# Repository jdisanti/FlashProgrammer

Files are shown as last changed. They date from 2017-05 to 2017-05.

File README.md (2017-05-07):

128KiB 17-bit Addressed 32-pin Flash ROM Programmer
---------------------------------------------------

Flash Programmer

This package includes the schematic, PCB design, and software for an USB
Flash Programmer to read/write the contents of 128KiB 32-pin Flash ROM chips,
such as the GLS27SF010 by Greenliant.

This is my second electronics project, and a stepping stone to building my
own 8-bit computer. I made a lot of mistakes along the way and learned a ton.
After four PCB revisions, and hours of frustrating debugging, I finally got it
to successfully erase, write, and verify the contents of a ROM.

## Demo

flash_programmer_software_anim

## Project Structure

The `avr/` directory contains all of the software to be run on the Atmel
ATMEGA328 chip on the board. This needs to be compiled and programmed onto
the board using an ISP on the ISP headers.

The `design/` directory contains the schematic and PCB design in the original
KiCad file formats. The BOM file is also here.

The `PDFs/` directory contains PDF output for the schematic and PCB.

The `software/` directory contains the software that runs on the PC to
communicate with the device over USB serial. It's written in Rust and can
be compiled/run on Linux, Mac, and Windows without a hitch.

Finally, `symbol_generation/` contains some CSV files used to generate
schematic symbols with KiPart.

## What I Learned

This project presented a lot of firsts for me. My previous project, a binary
clock, had taught me how to design a digital circuit with a microcontroller,
draw schematics, and create PCBs.

This project, above all other things, taught me patience. If you read the
next section about the mistakes I made, you'll see why. I learned that I
really need to slow down, be sure to read all of the datasheets, double
check my schematics and footprints, and cross-check my schematic against
the datasheets. Then after all of that, wait a week and then do it again.

Coming from a software background made this a very hard lesson. I'm used to
making small incremental changes and getting test results immediately. Working
in an area where incremental changes are expensive, and where testing is
time-consuming, requires a difficult change of mindset.

Something I didn't do with this project was breadboarding. I wanted to see
if I could design and build a working circuit without that step. I've learned
that I can play around with little "mock" circuits in LTSpice to test some
of my assumptions, and then also build those out on breadboard without having
to build the entire circuit. This was useful for designing the A9 signal/12V
switching circuit.

## Mistakes I Made

Since the goal of this project was to learn, I've decided to document all
the mistakes I made for future reference.

**First board (not in version control)**
- I didn't read the entire datasheet for the MAX662A, and thus, didn't realize
  I needed capacitors on the 12V output. This led to there being no 12V supply
  on that board.
- I tried to be clever and soldered the board up in sections so I could test each
  individually. This is how I discovered the 12V supply wasn't working, but I didn't
  continue testing the other sections after that discovery, and thus, didn't
  discover my next mistake until the next board.

**Second board**
- I got the pins on the SOT-23 2N3906 transistor wrong, and lost a decent
  chunk of time debugging that, and then soldering it on upside-down to fix it.
- I discovered that I couldn't use the daisy chaining pin on the 74HC595
  as the 17th bit of the address. I should have looked at the timing diagram
  in the datasheet to verify my assumption. I was actually able to bodge this
  by severing the A16 line and wiring it to the three unused pins on the micro
  (and setting all three pins to the same output since they were tied together).
- I used the ISP pins for both programming the MCU and talking to the ROM chip,
  but I neglected to add resistors so that I could program the MCU while the
  ROM chip was populated on the board. Unfortunately, I didn't realize this at
  the time, and thought I had fried my MCU somehow. Since I had already discovered
  the address line mistake, I just built another revision instead of doing
  more testing (I didn't have a rework station at the time and didn't want to
  solder another board either).

**Third board**
- I discovered that erasing didn't work because I failed to realize that
  the 12V had to be applied to both the VPP and A9 pins during the erase process.

**Fourth board**
- I didn't put a pull-down resistor on the A9 signal after the diodes. This
  forced me to add a hefty delay loop of 160uS in the code that set the address.
  This mistake is still present in the design since it wasn't fatal.

## License

All of the contents of this package are licensed under the Solderpad 0.51
license. Please read the LICENSE.md included for more details.

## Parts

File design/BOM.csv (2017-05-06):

Id | Designator | Package | Quantity | Designation | Supplier and ref
1 | P601 | Pin_Header_Straight_2x03_Pitch2.54mm | 1 | ISP
2 | P201 | USB_B | 1 | USB_B
3 | Q301 | SOT-23_Handsoldering | 1 | 2N3904
4 | D301,D302 | D_SOT-23_ANK | 2 | BAT54
5 | C201,C206,C301,C501,C502,C601,C602,C603 | R_0603_HandSoldering | 8 | 100nF
6 | C202 | R_0603_HandSoldering | 1 | 10nF
7 | C203,C401,C402 | R_0805_HandSoldering | 3 | 4.7uF
8 | C204,C205 | R_0603_HandSoldering | 2 | 47pF
9 | C403,C404 | R_0603_HandSoldering | 2 | 22nF
10 | D701,D702,D703 | LED_0805 | 3 | LED
11 | L201 | R_0805_HandSoldering | 1 | Ferrite_Bead
12 | Q701 | SOT-23_Handsoldering | 1 | 2N3906
13 | R201,R202 | R_0603_HandSoldering | 2 | 27
14 | R301 | R_0603_HandSoldering | 1 | 1k
15 | R302,R501,R502,R602,R704 | R_0603_HandSoldering | 5 | 10k
16 | R601,R603,R604,R605 | R_0603_HandSoldering | 4 | 4.7k
17 | R701,R702,R703 | R_0603_HandSoldering | 3 | 150
18 | U201 | SSOP-16 | 1 | FT230X
19 | U301 | DIP-32_W15.24mm | 1 | GLS27SF010
20 | U401 | SOIC-8_3.9x4.9mm_Pitch1.27mm | 1 | MAX662A
21 | U501,U502 | SOIC-16_3.9x9.9mm_Pitch1.27mm | 2 | 74HC595
22 | U601 | TQFP-32 | 1 | ATMEGA328-AU

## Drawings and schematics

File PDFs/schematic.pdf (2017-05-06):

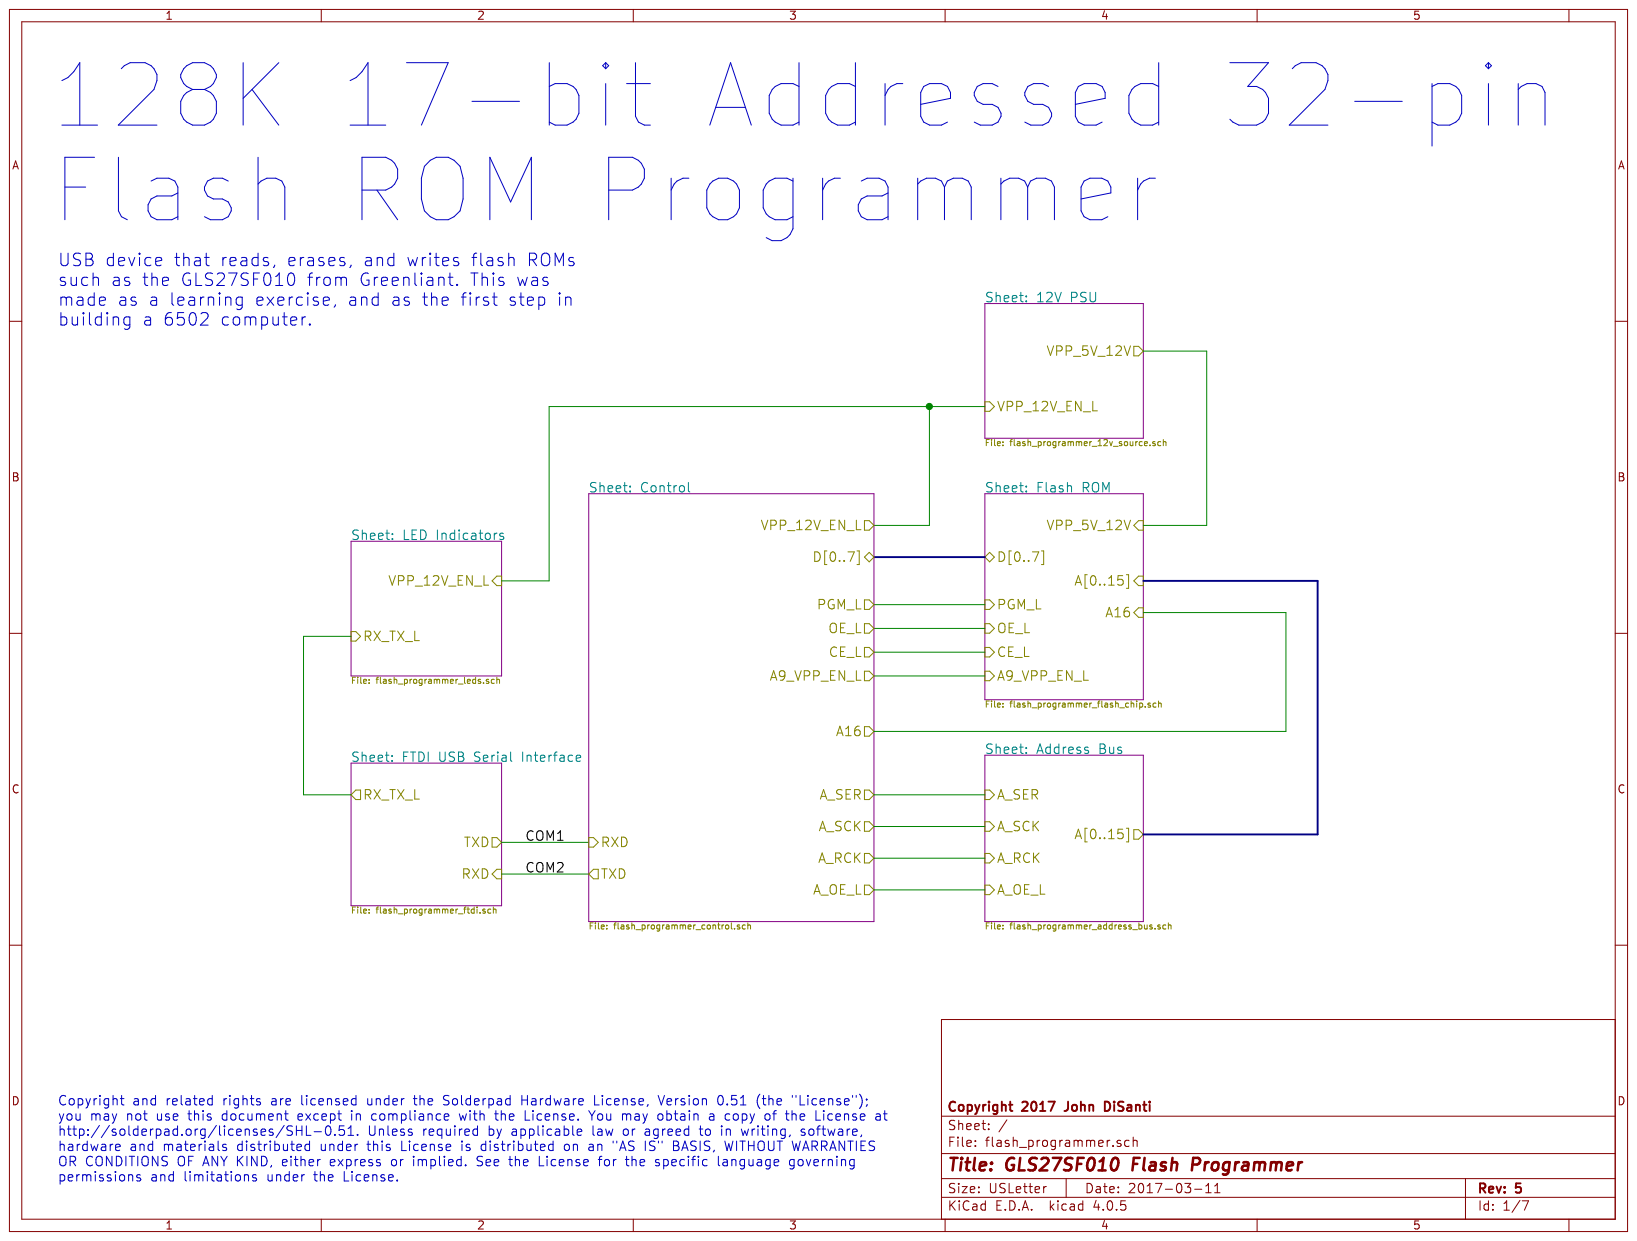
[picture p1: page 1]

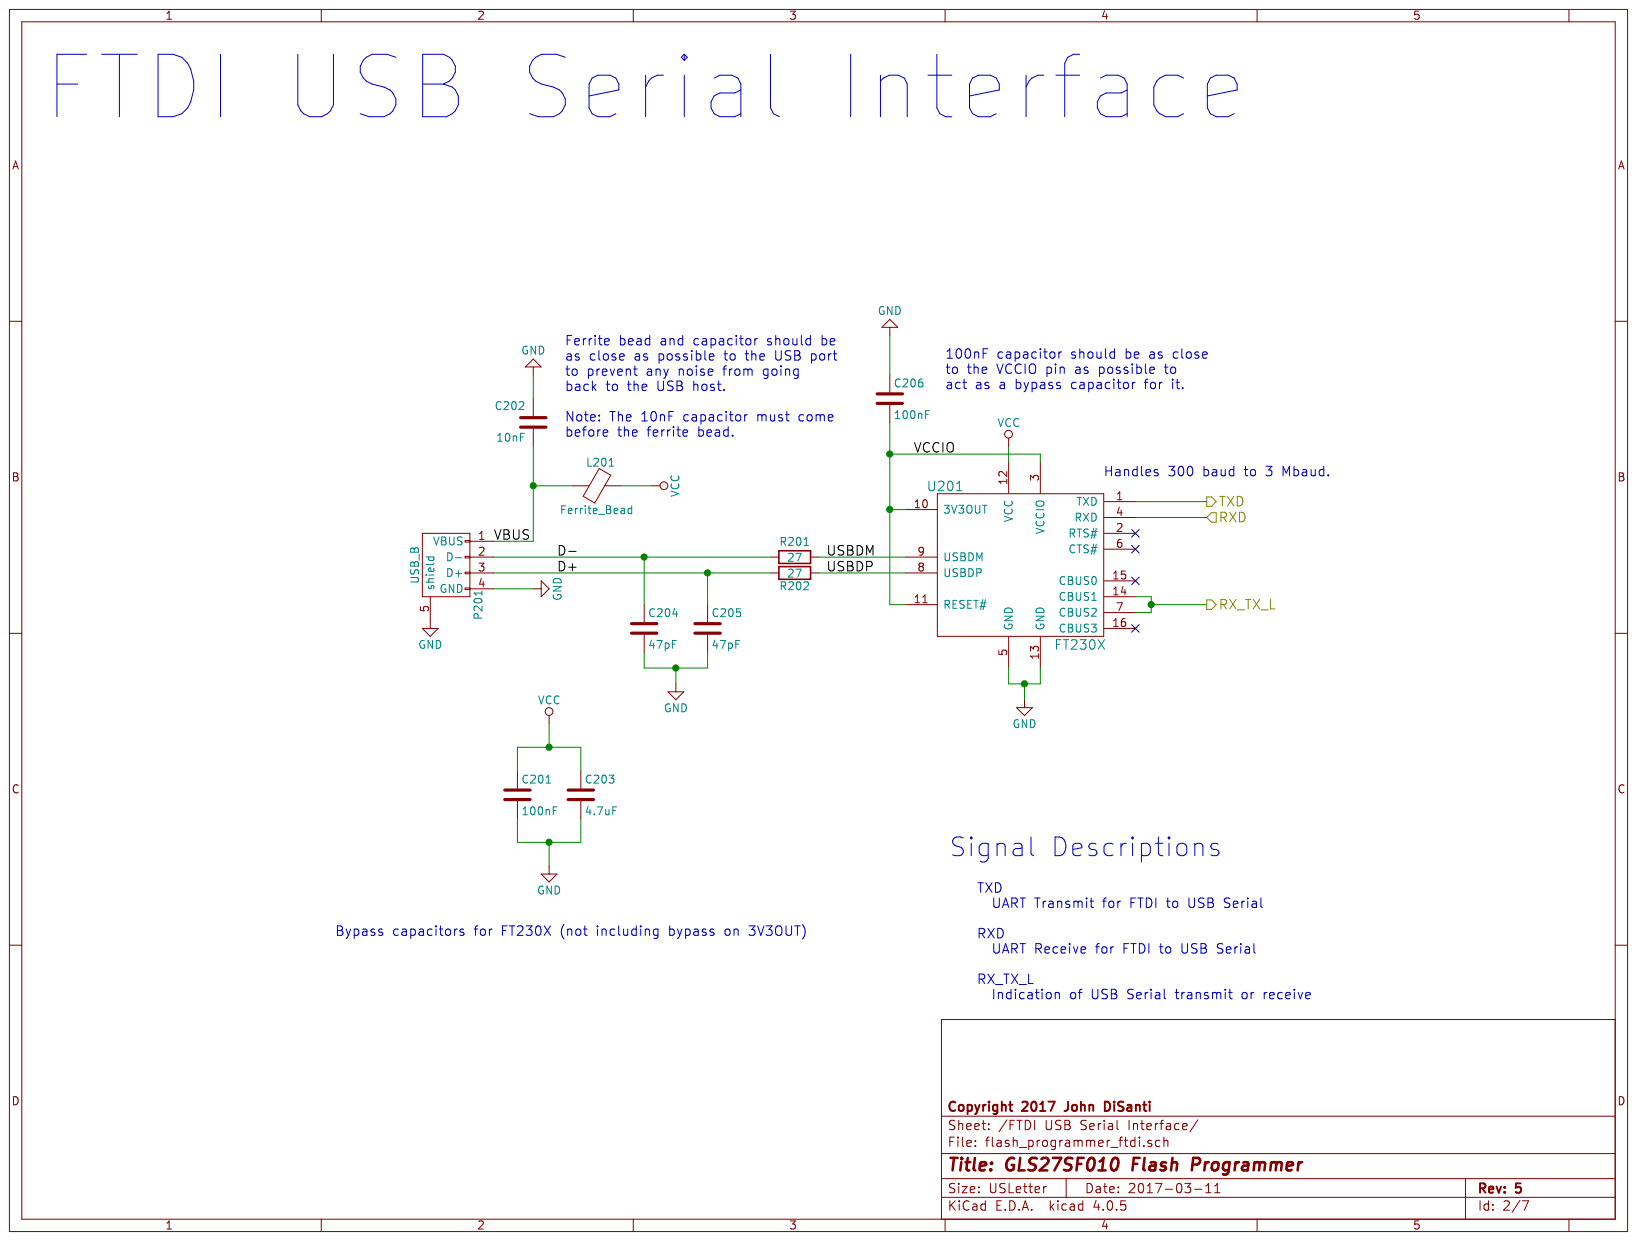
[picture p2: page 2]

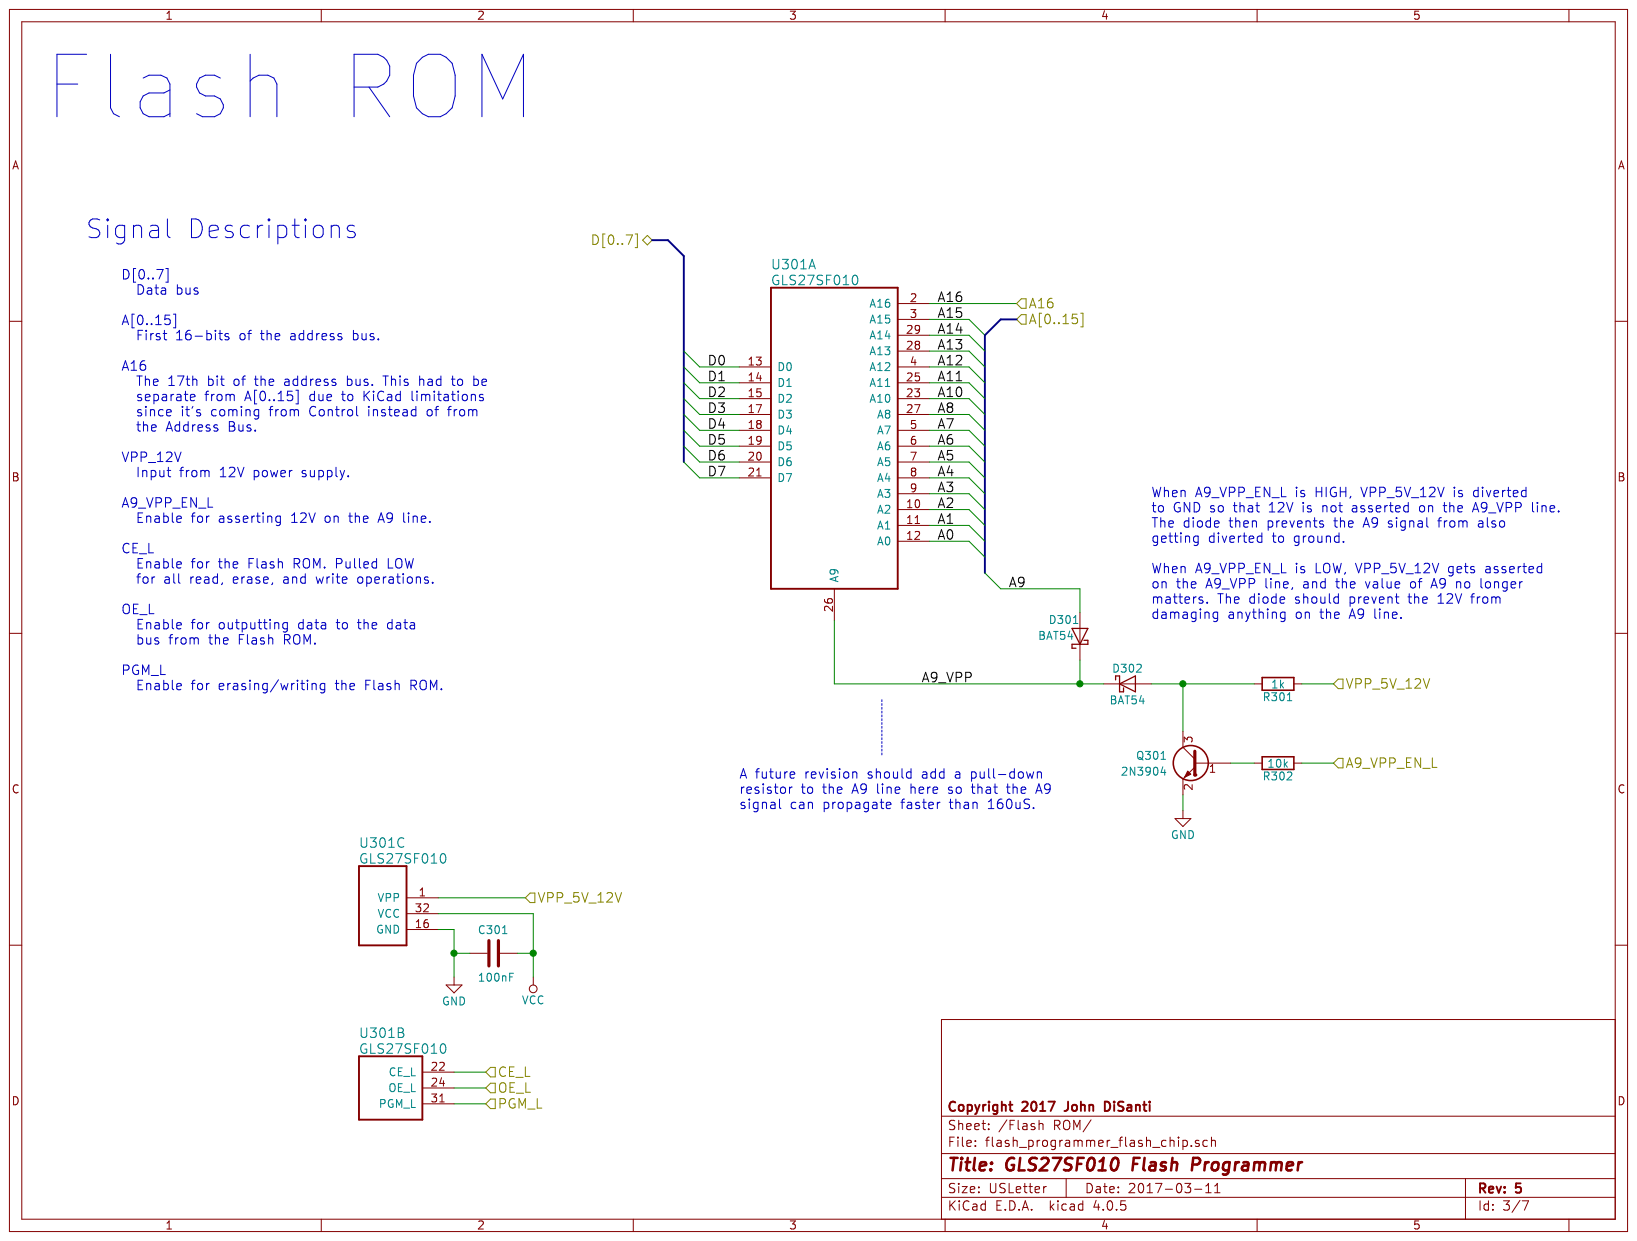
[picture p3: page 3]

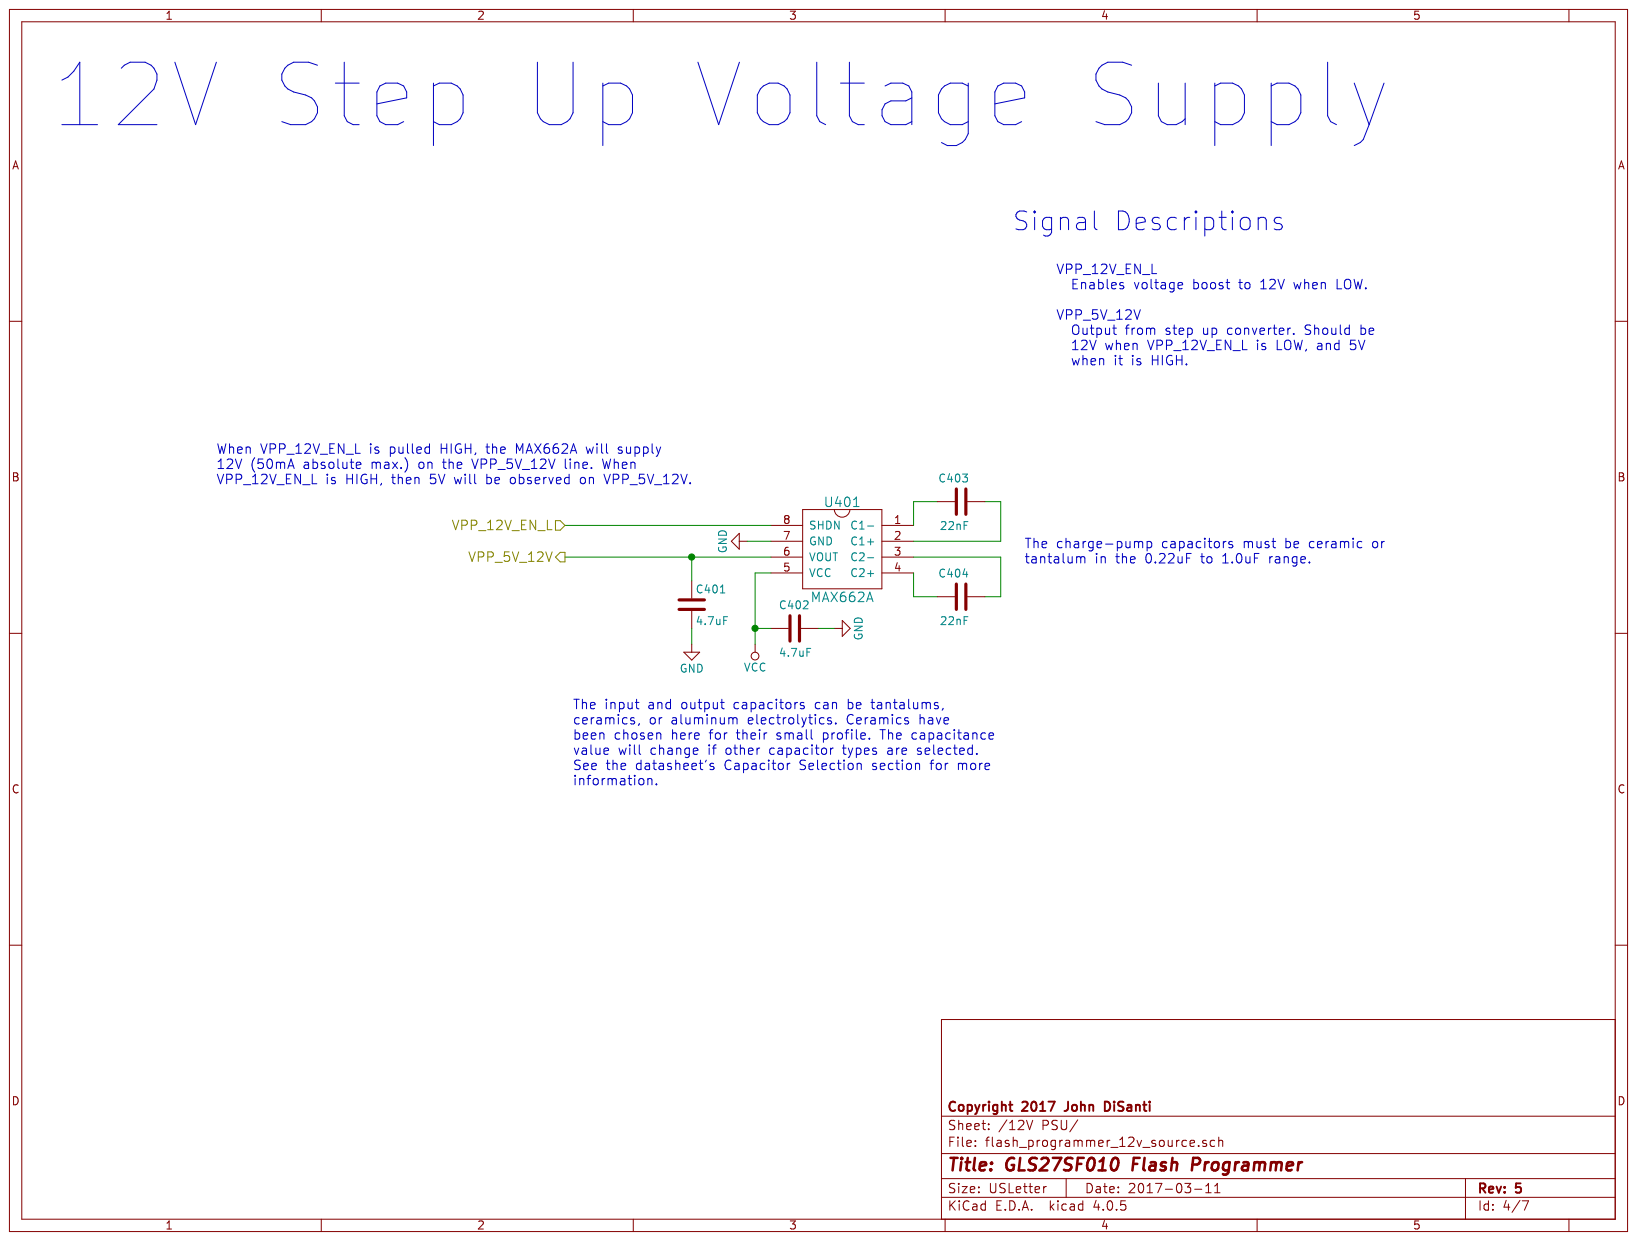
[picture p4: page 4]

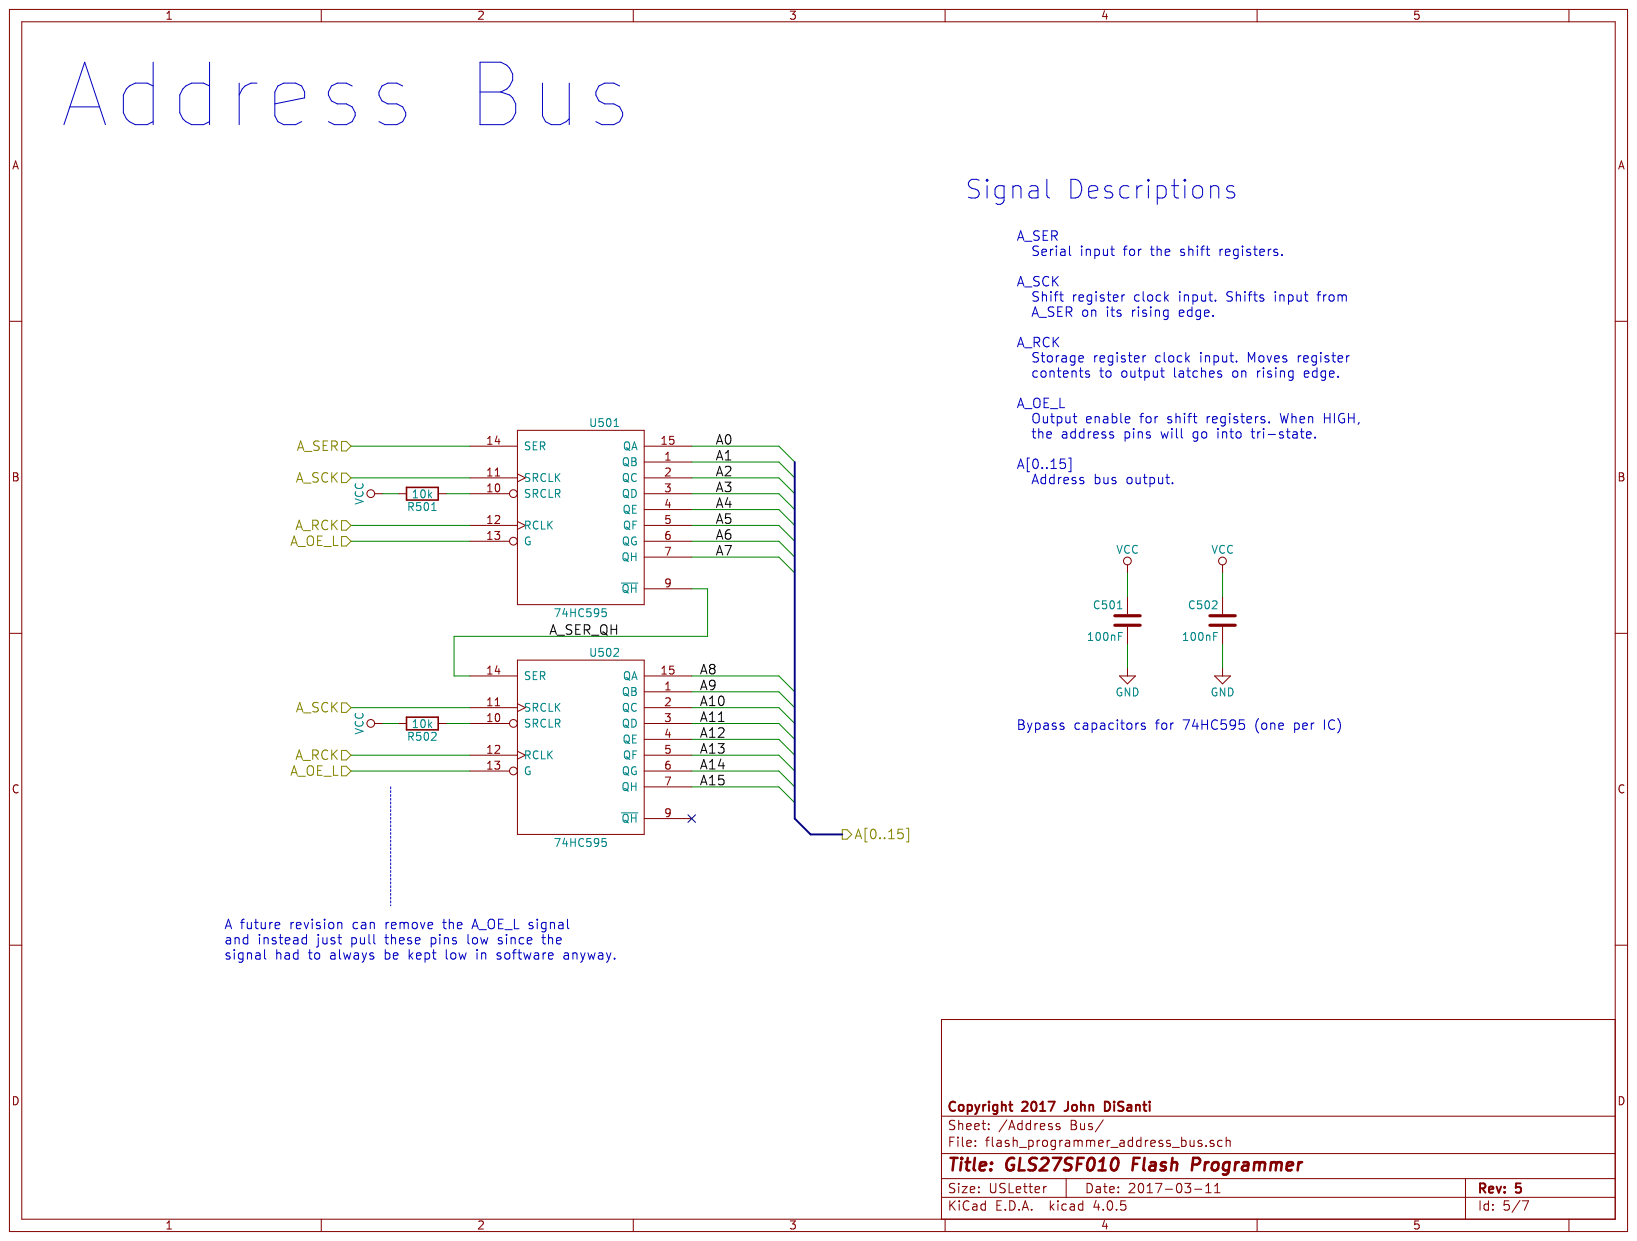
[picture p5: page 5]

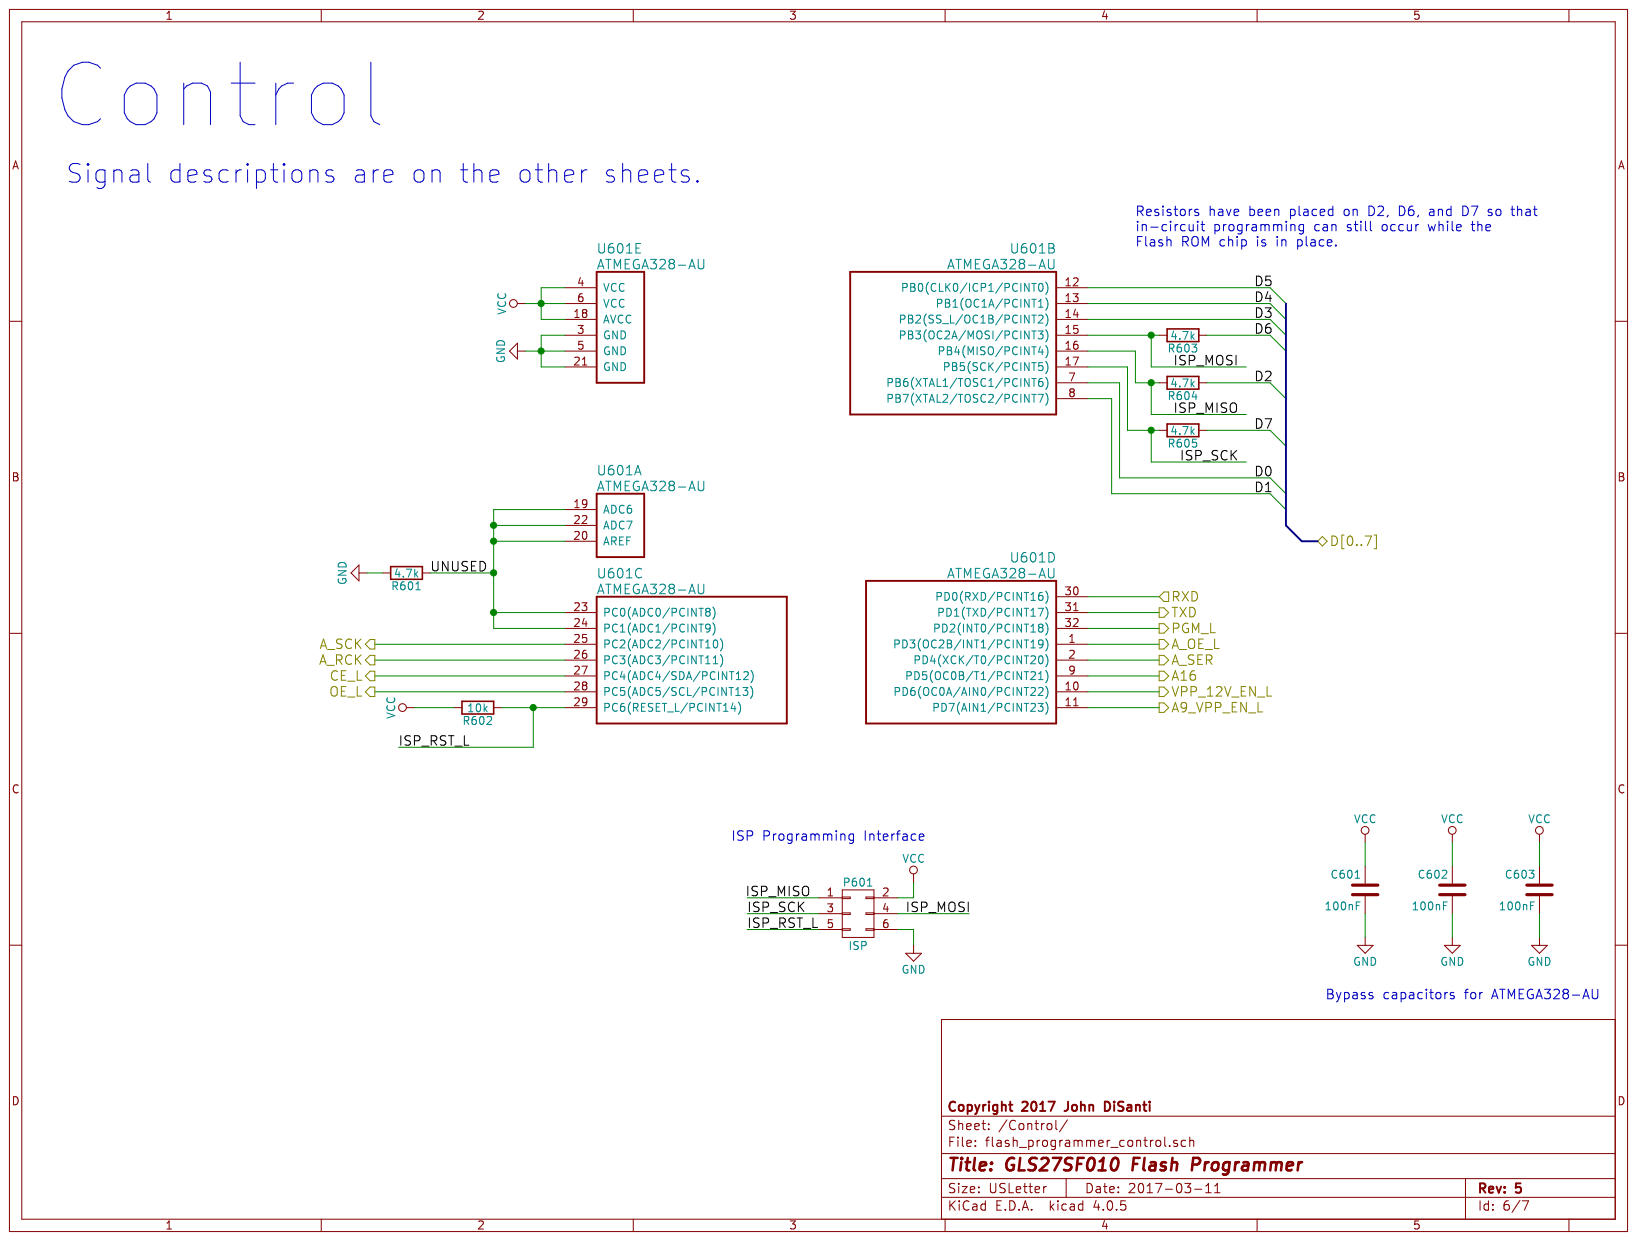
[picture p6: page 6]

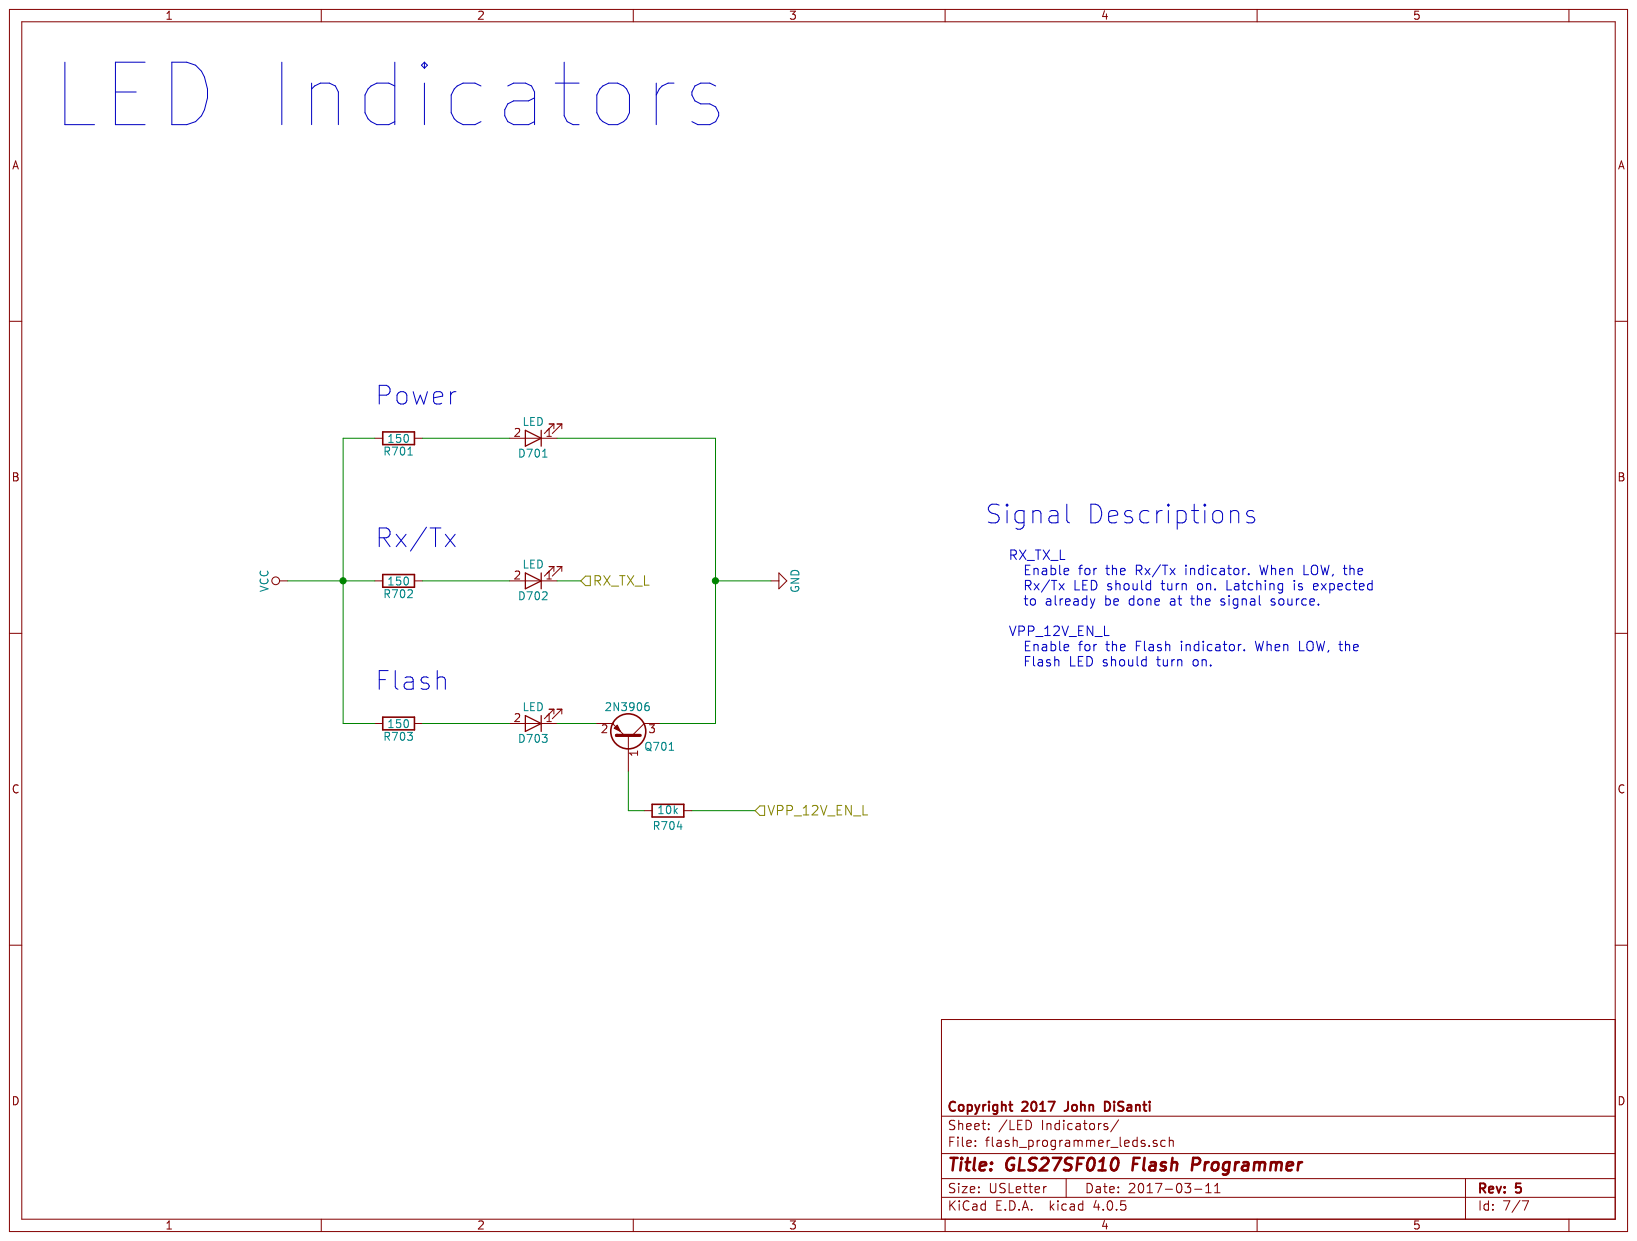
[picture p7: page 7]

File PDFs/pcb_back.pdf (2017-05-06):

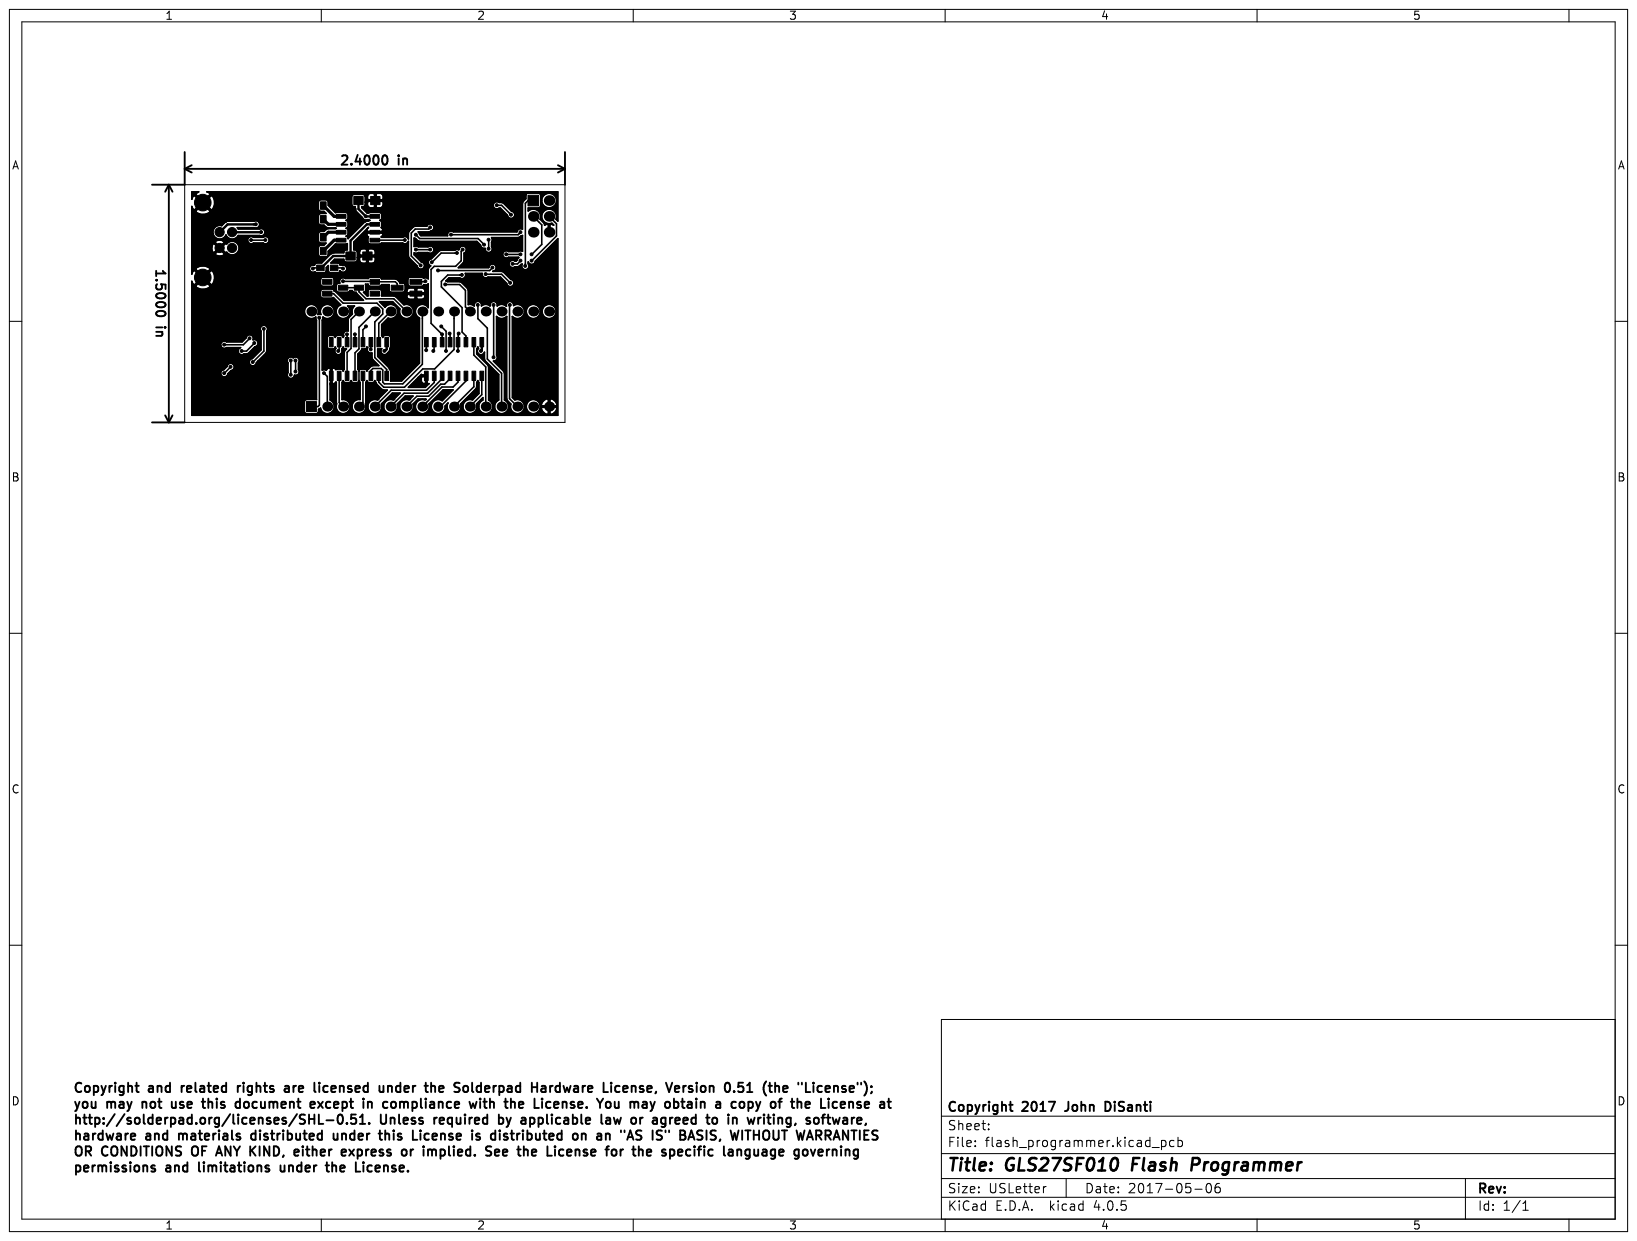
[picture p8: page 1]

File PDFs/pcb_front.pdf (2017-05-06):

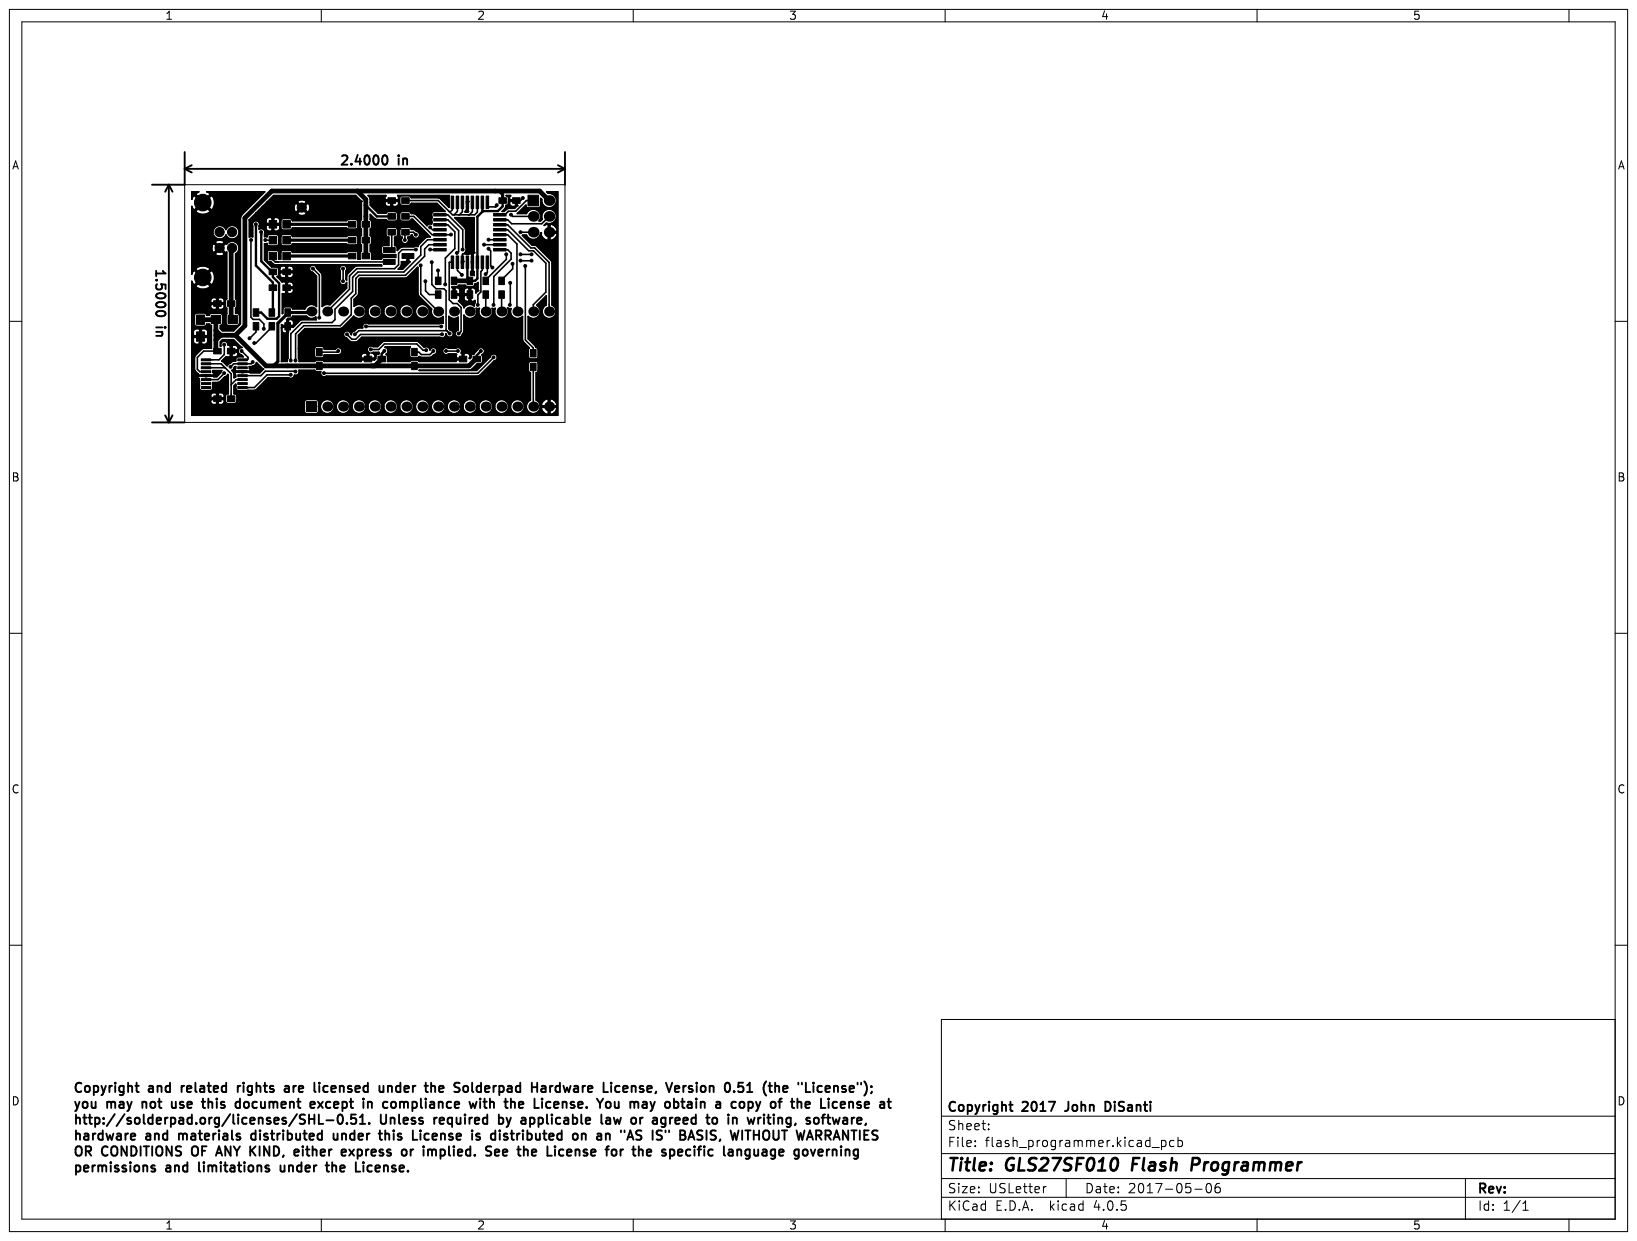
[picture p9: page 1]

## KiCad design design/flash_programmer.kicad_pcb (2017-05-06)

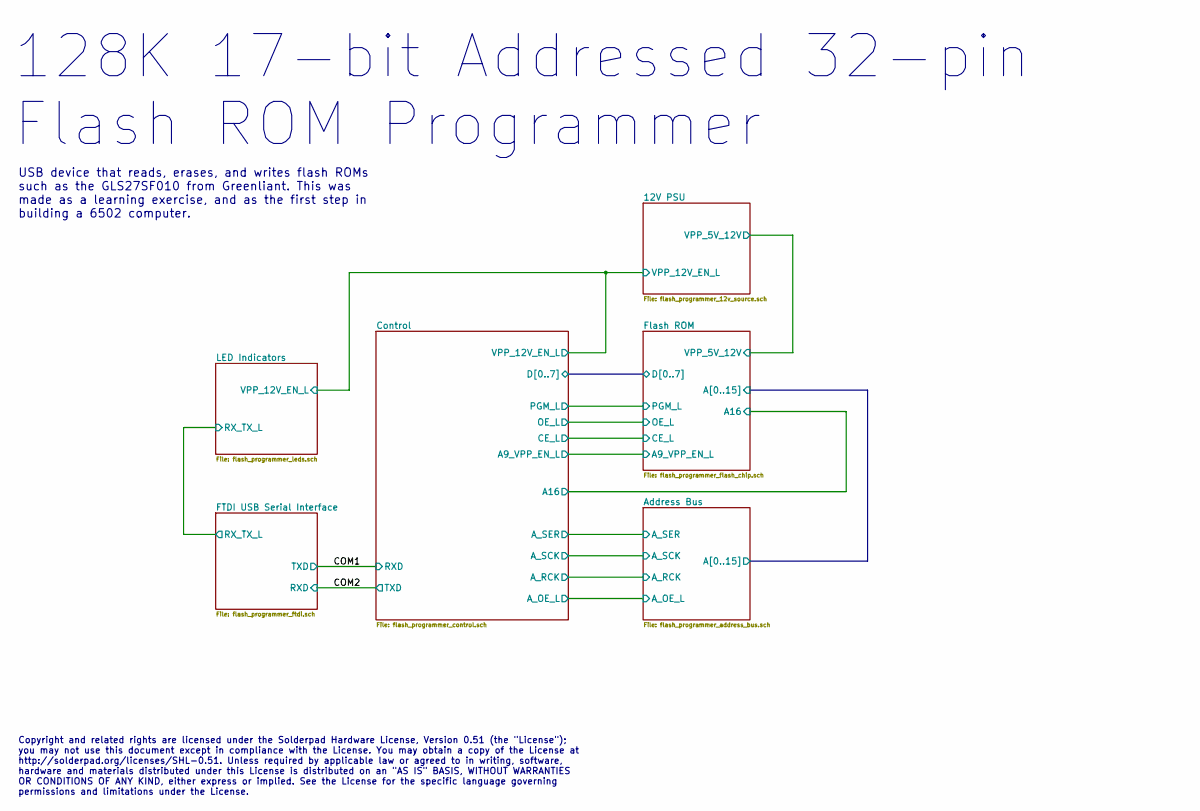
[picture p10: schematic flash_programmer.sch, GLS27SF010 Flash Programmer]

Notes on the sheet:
128K 17-bit Addressed 32-pin Flash ROM Programmer
USB device that reads, erases, and writes flash ROMs such as the GLS27SF010 from Greenliant. This was made as a learning exercise, and as the first step in building a 6502 computer.
Copyright and related rights are licensed under the Solderpad Hardware License, Version 0.51 (the "License"); you may not use this document except in compliance with the License. You may obtain a copy of the License at http://solderpad.org/licenses/SHL-0.51. Unless required by applicable law or agr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

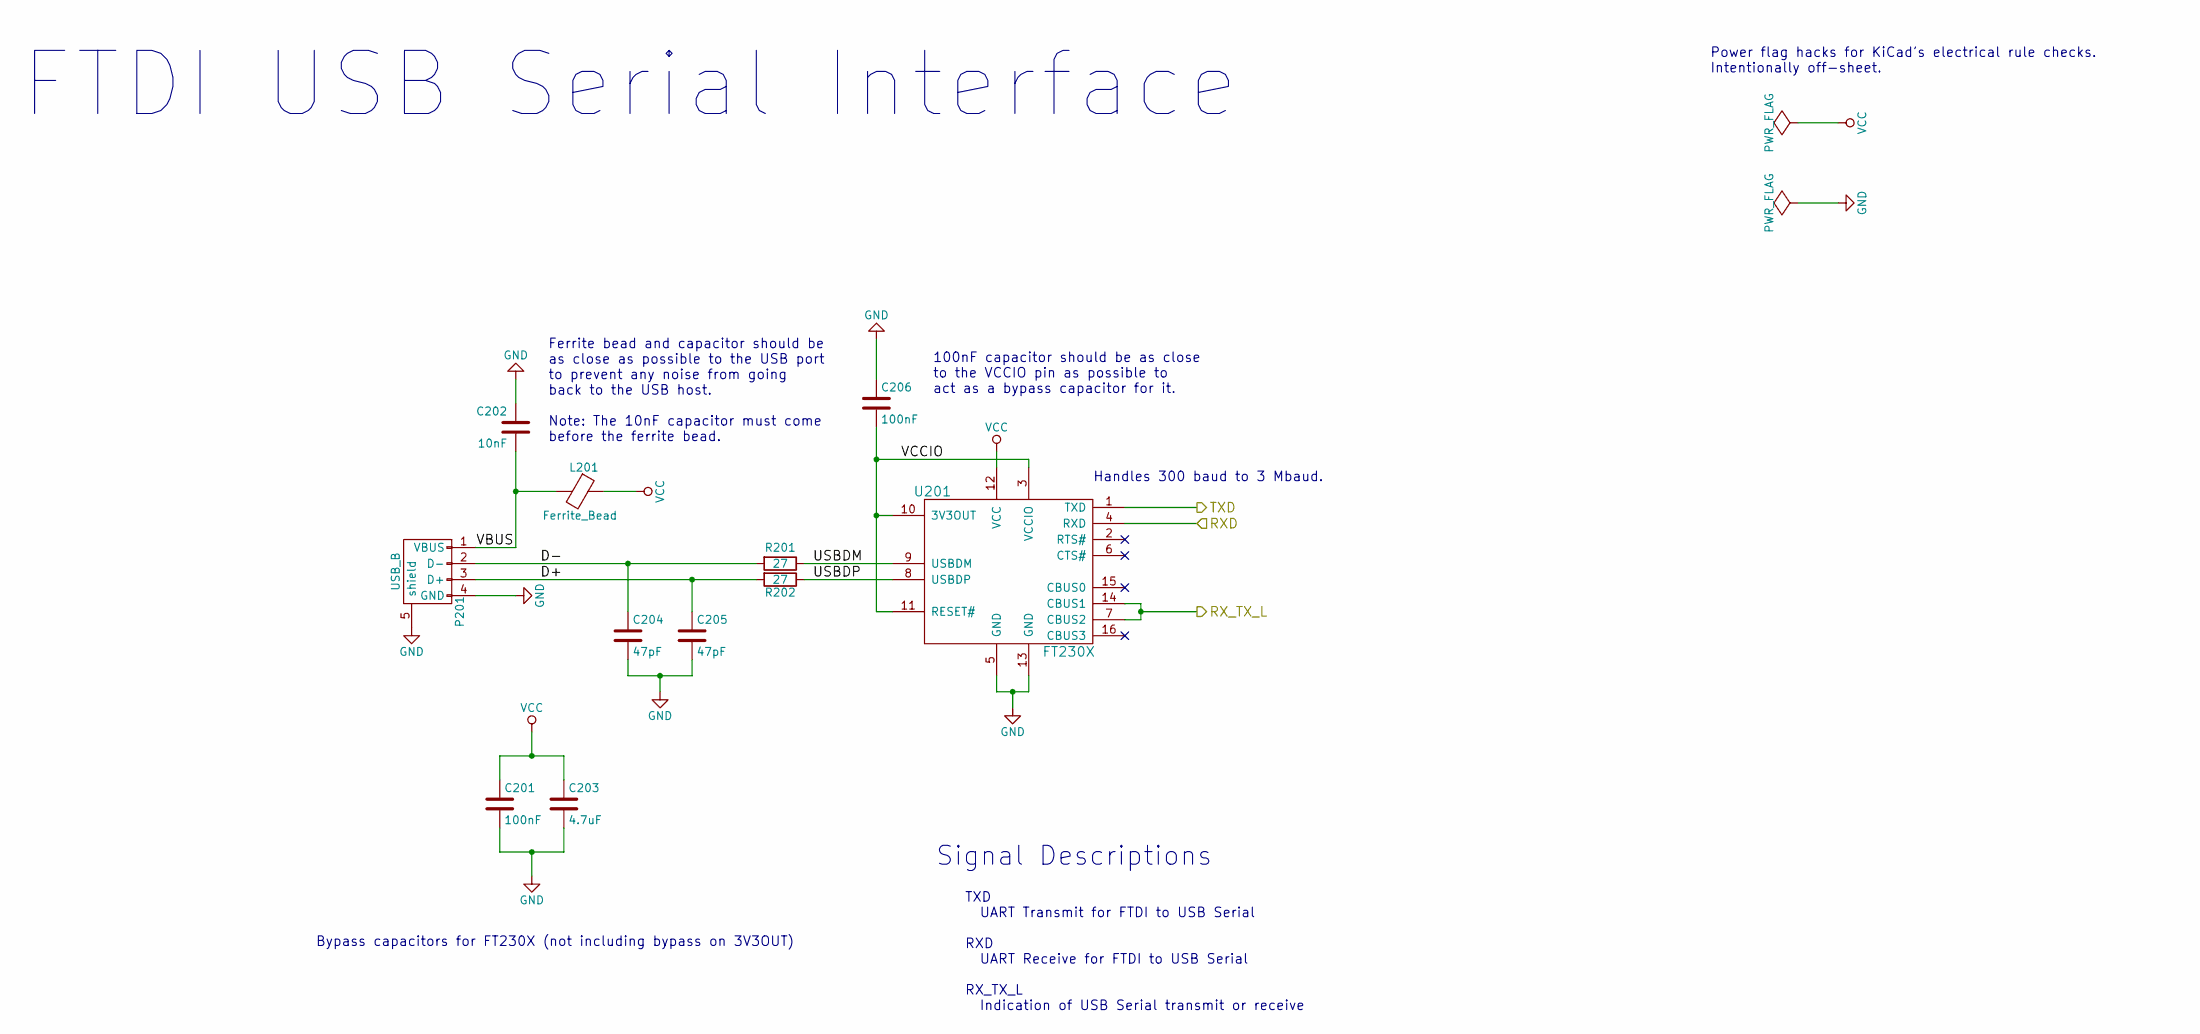
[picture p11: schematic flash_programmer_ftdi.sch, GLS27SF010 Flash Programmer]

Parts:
C201, C206: 100nF; R_0603_HandSoldering
C202: 10nF; R_0603_HandSoldering
C203: 4.7uF; R_0805_HandSoldering
C204, C205: 47pF; R_0603_HandSoldering
L201: Ferrite_Bead; R_0805_HandSoldering
P201: USB_B
R201, R202: 27; R_0603_HandSoldering
U201: FT230X; SSOP-16

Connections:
/COM1: U201.1 (TXD); also elsewhere on the board
/COM2: U201.4 (RXD); also elsewhere on the board
/FTDI USB Serial Interface/D+: C205.1, P201.3 (D+), R202.2
/FTDI USB Serial Interface/D-: C204.1, P201.2 (D-), R201.2
/FTDI USB Serial Interface/RX_TX_L: U201.7 (CBUS2), U201.14 (CBUS1); also elsewhere on the board
/FTDI USB Serial Interface/USBDM: R201.1, U201.9 (USBDM)
/FTDI USB Serial Interface/USBDP: R202.1, U201.8 (USBDP)
/FTDI USB Serial Interface/VBUS: C202.1, L201.2, P201.1 (VBUS)
/FTDI USB Serial Interface/VCCIO: C206.2, U201.3 (VCCIO), U201.10 (3V3OUT), U201.11 (RESET#)
GND: C201.2, C202.2, C203.2, C204.2, C205.2, C206.1, P201.4 (GND), P201.5 (shield), U201.5 (GND), U201.13 (GND); also elsewhere on the board
VCC: C201.1, C203.1, L201.1, U201.12 (VCC); also elsewhere on the board

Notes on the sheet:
Bypass capacitors for FT230X (not including bypass on 3V3OUT)
Ferrite bead and capacitor should be as close as possible to the USB port to prevent any noise from going back to the USB host. Note: The 10nF capacitor must come before the ferrite bead.
100nF capacitor should be as close to the VCCIO pin as possible to act as a bypass capacitor for it.
Power flag hacks for KiCad's electrical rule checks. Intentionally off-sheet.
FTDI USB Serial Interface
Signal Descriptions
TXD UART Transmit for FTDI to USB Serial RXD UART Receive for FTDI to USB Serial RX_TX_L Indication of USB Serial transmit or receive
Handles 300 baud to 3 Mbaud.

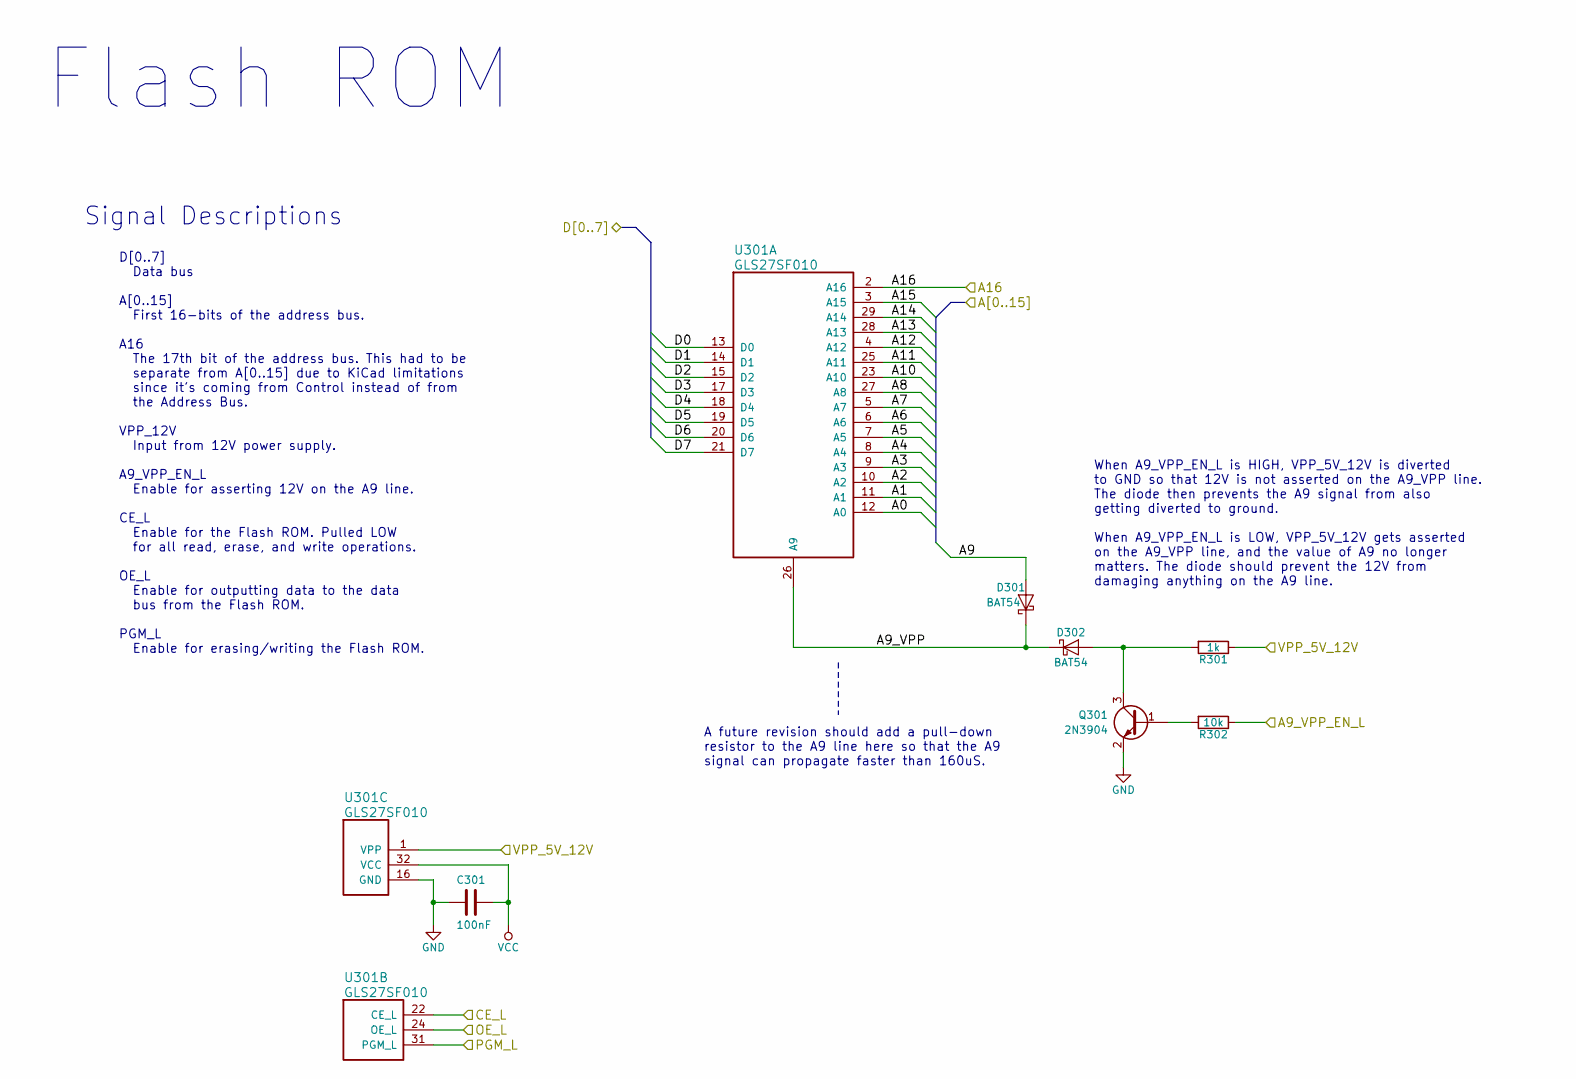
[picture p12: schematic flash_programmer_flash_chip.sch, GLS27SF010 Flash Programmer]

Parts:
C301: 100nF; R_0603_HandSoldering
D301, D302: BAT54; D_SOT-23_ANK
Q301: 2N3904; SOT-23_Handsoldering
R301: 1k; R_0603_HandSoldering
R302: 10k; R_0603_HandSoldering
U301: GLS27SF010; DIP-32_W15.24mm

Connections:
/12V PSU/VPP_5V_12V: R301.1, U301.1 (VPP); also elsewhere on the board
/Address Bus/A0: U301.12 (A0); also elsewhere on the board
/Address Bus/A1: U301.11 (A1); also elsewhere on the board
/Address Bus/A2: U301.10 (A2); also elsewhere on the board
/Address Bus/A3: U301.9 (A3); also elsewhere on the board
/Address Bus/A4: U301.8 (A4); also elsewhere on the board
/Address Bus/A5: U301.7 (A5); also elsewhere on the board
/Address Bus/A6: U301.6 (A6); also elsewhere on the board
/Address Bus/A7: U301.5 (A7); also elsewhere on the board
/Address Bus/A8: U301.27 (A8); also elsewhere on the board
/Address Bus/A9: D301.2 (A); also elsewhere on the board
/Address Bus/A10: U301.23 (A10); also elsewhere on the board
/Address Bus/A11: U301.25 (A11); also elsewhere on the board
/Address Bus/A12: U301.4 (A12); also elsewhere on the board
/Address Bus/A13: U301.28 (A13); also elsewhere on the board
/Address Bus/A14: U301.29 (A14); also elsewhere on the board
/Address Bus/A15: U301.3 (A15); also elsewhere on the board
/Control/A9_VPP_EN_L: R302.1; also elsewhere on the board
/Control/A16: U301.2 (A16); also elsewhere on the board
/Control/CE_L: U301.22 (CE_L); also elsewhere on the board
/Control/D0: U301.13 (D0); also elsewhere on the board
/Control/D1: U301.14 (D1); also elsewhere on the board
/Control/D2: U301.15 (D2); also elsewhere on the board
/Control/D3: U301.17 (D3); also elsewhere on the board
/Control/D4: U301.18 (D4); also elsewhere on the board
/Control/D5: U301.19 (D5); also elsewhere on the board
/Control/D6: U301.20 (D6); also elsewhere on the board
/Control/D7: U301.21 (D7); also elsewhere on the board
/Control/OE_L: U301.24 (OE_L); also elsewhere on the board
/Control/PGM_L: U301.31 (PGM_L); also elsewhere on the board
/Flash ROM/A9_VPP: D301.1 (K), D302.1 (K), U301.26 (A9)
GND: C301.2, Q301.2 (E), U301.16 (GND); also elsewhere on the board
unnamed: D302.2 (A), Q301.3 (C), R301.2
unnamed: Q301.1 (B), R302.2
VCC: C301.1, U301.32 (VCC); also elsewhere on the board

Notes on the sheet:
Flash ROM
When A9_VPP_EN_L is HIGH, VPP_5V_12V is diverted to GND so that 12V is not asserted on the A9_VPP line. The diode then prevents the A9 signal from also getting diverted to ground. When A9_VPP_EN_L is LOW, VPP_5V_12V gets asserted on the A9_VPP line, and the value of A9 no longer matters. The diode 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
D[0..7] Data bus A[0..15] First 16-bits of the address bus. A16 The 17th bit of the address bus. This had to be separate from A[0..15] due to KiCad limitations since it's coming from Control instead of from the Address Bus. VPP_12V Input from 12V power supply. A9_VPP_EN_L Enable for asserting 12V o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
Signal Descriptions
A future revision should add a pull-down resistor to the A9 line here so that the A9 signal can propagate faster than 160uS.

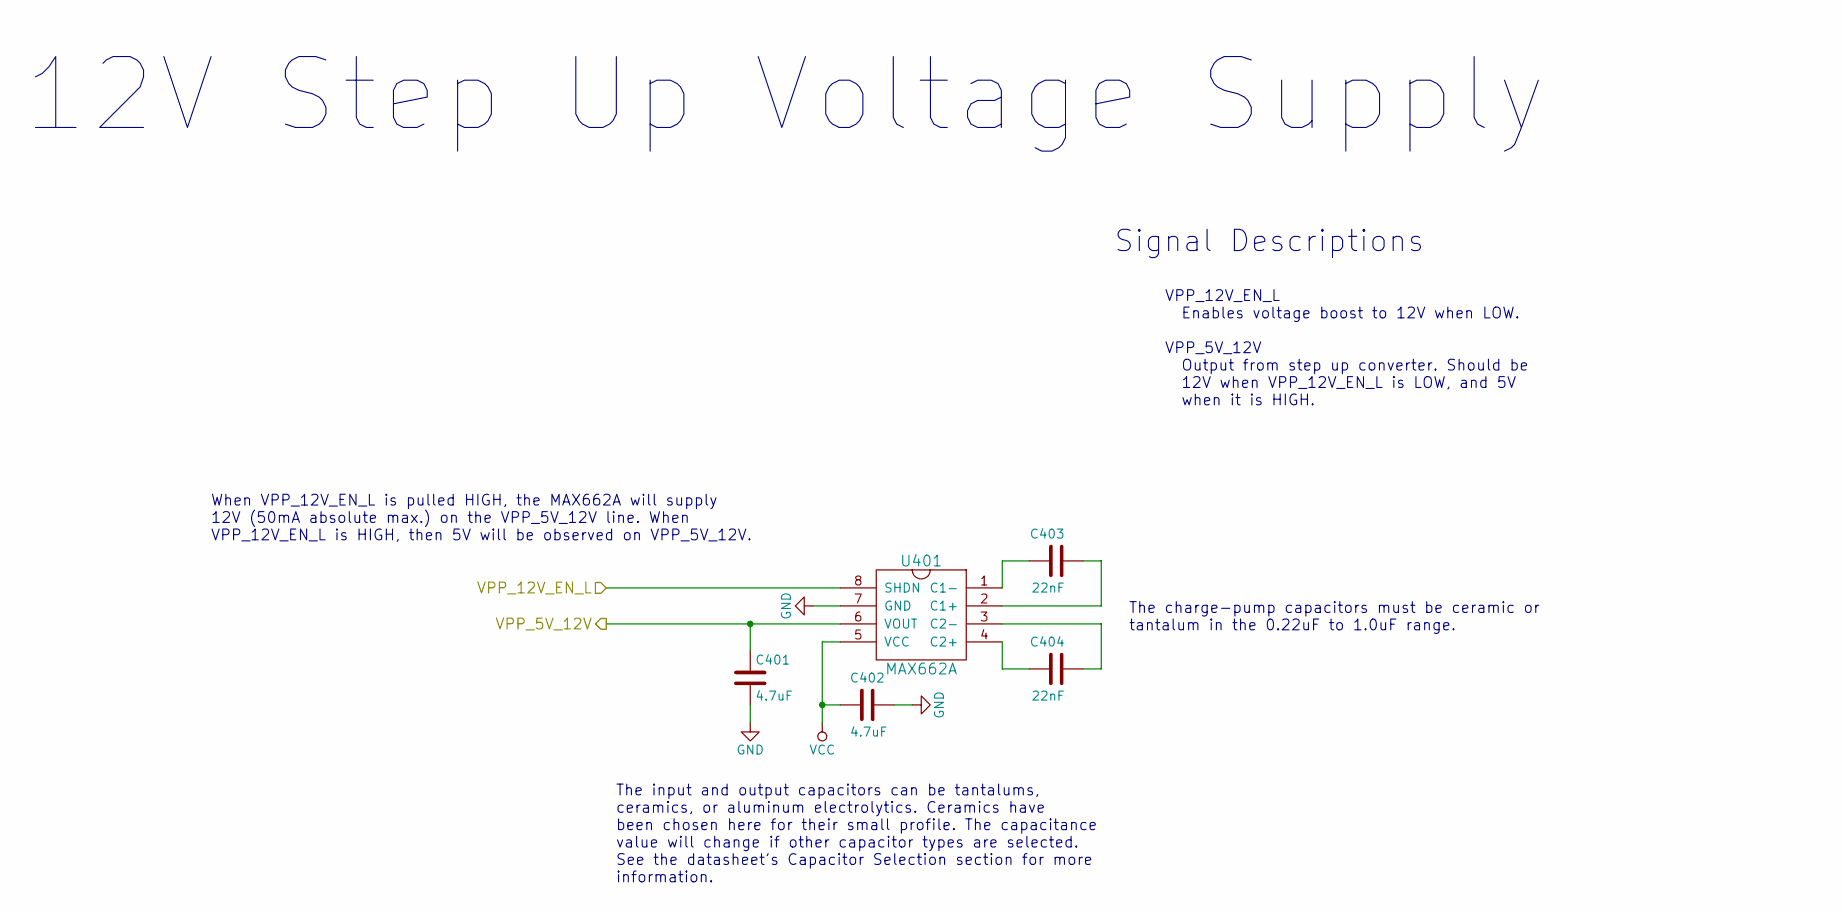
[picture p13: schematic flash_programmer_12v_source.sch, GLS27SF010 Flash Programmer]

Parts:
C401, C402: 4.7uF; R_0805_HandSoldering
C403, C404: 22nF; R_0603_HandSoldering
U401: MAX662A; SOIC-8_3.9x4.9mm_Pitch1.27mm

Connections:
/12V PSU/VPP_5V_12V: C401.1, U401.6 (VOUT); also elsewhere on the board
/12V PSU/VPP_12V_EN_L: U401.8 (SHDN); also elsewhere on the board
GND: C401.2, C402.1, U401.7 (GND); also elsewhere on the board
unnamed: C403.1, U401.1 (C1-)
unnamed: C403.2, U401.2 (C1+)
unnamed: C404.1, U401.4 (C2+)
unnamed: C404.2, U401.3 (C2-)
VCC: C402.2, U401.5 (VCC); also elsewhere on the board

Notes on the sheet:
12V Step Up Voltage Supply
When VPP_12V_EN_L is pulled HIGH, the MAX662A will supply 12V (50mA absolute max.) on the VPP_5V_12V line. When VPP_12V_EN_L is HIGH, then 5V will be observed on VPP_5V_12V.
The charge-pump capacitors must be ceramic or tantalum in the 0.22uF to 1.0uF range.
The input and output capacitors can be tantalums, ceramics, or aluminum electrolytics. Ceramics have been chosen here for their small profile. The capacitance value will change if other capacitor types are selected. See the datasheet's Capacitor Selection section for more information.
Signal Descriptions
VPP_12V_EN_L Enables voltage boost to 12V when LOW. VPP_5V_12V Output from step up converter. Should be 12V when VPP_12V_EN_L is LOW, and 5V when it is HIGH.

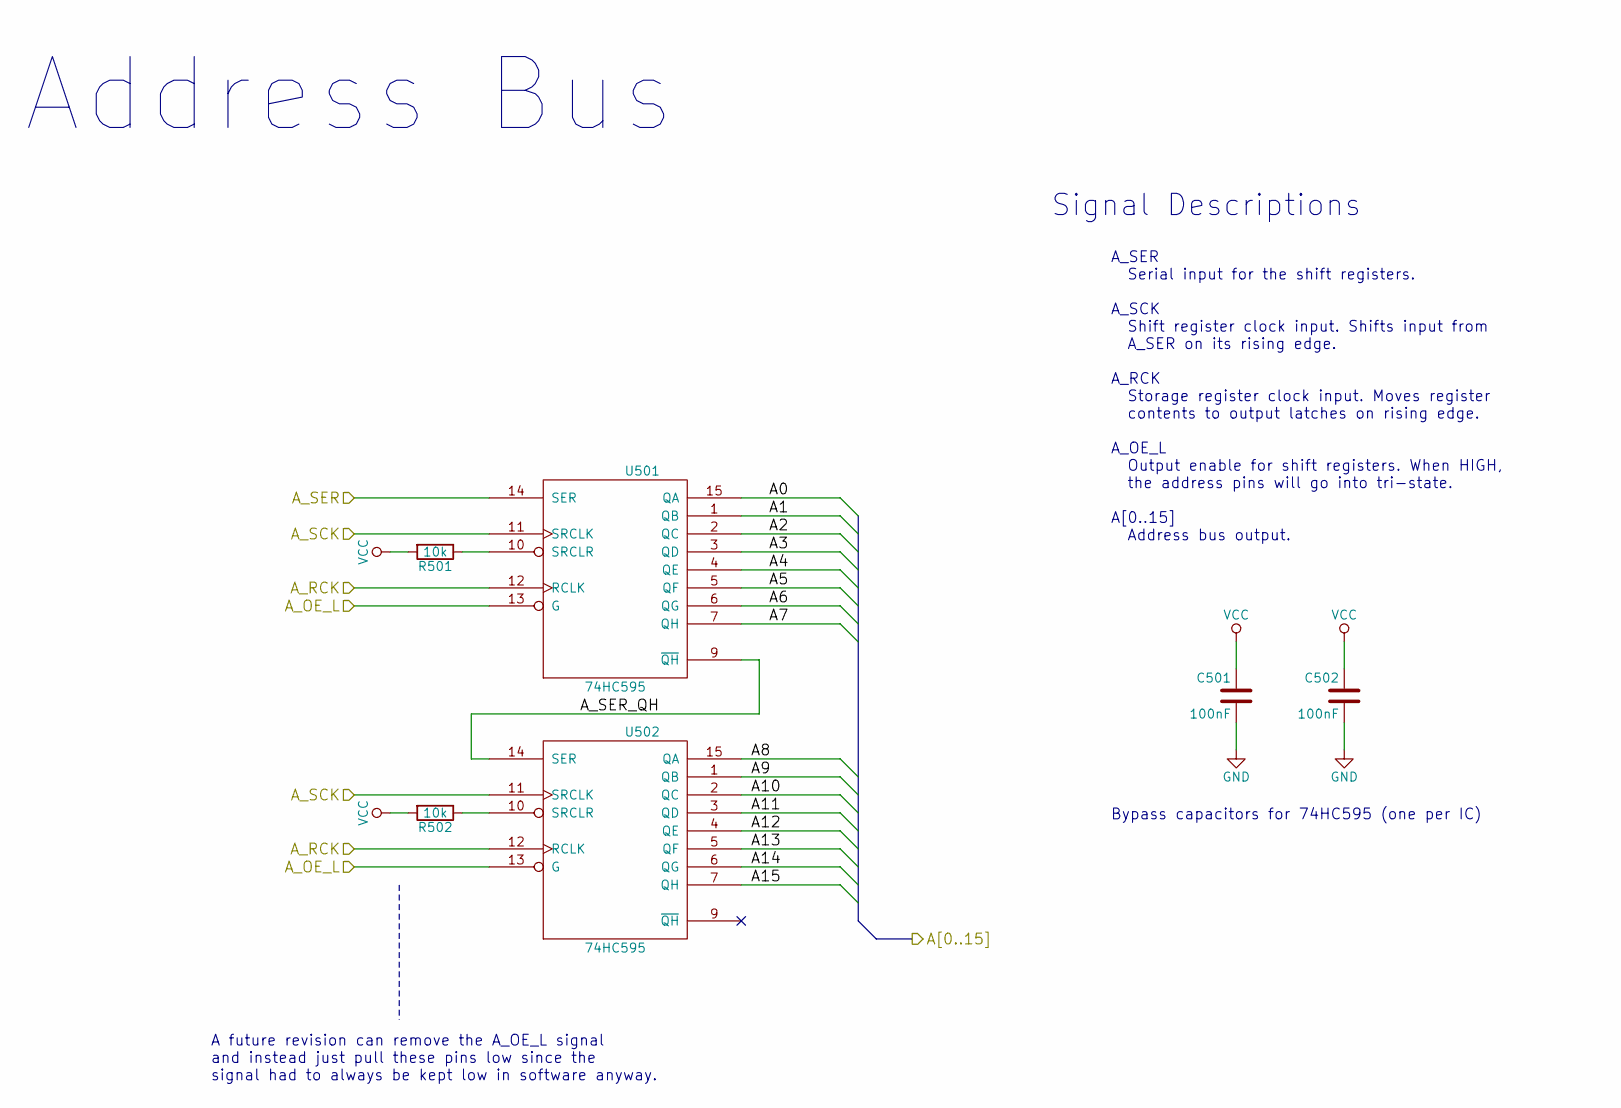
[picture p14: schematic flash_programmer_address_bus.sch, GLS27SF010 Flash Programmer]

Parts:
C501, C502: 100nF; R_0603_HandSoldering
R501, R502: 10k; R_0603_HandSoldering
U501, U502: 74HC595; SOIC-16_3.9x9.9mm_Pitch1.27mm

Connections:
/Address Bus/A0: U501.15 (QA); also elsewhere on the board
/Address Bus/A1: U501.1 (QB); also elsewhere on the board
/Address Bus/A2: U501.2 (QC); also elsewhere on the board
/Address Bus/A3: U501.3 (QD); also elsewhere on the board
/Address Bus/A4: U501.4 (QE); also elsewhere on the board
/Address Bus/A5: U501.5 (QF); also elsewhere on the board
/Address Bus/A6: U501.6 (QG); also elsewhere on the board
/Address Bus/A7: U501.7 (QH); also elsewhere on the board
/Address Bus/A8: U502.15 (QA); also elsewhere on the board
/Address Bus/A9: U502.1 (QB); also elsewhere on the board
/Address Bus/A10: U502.2 (QC); also elsewhere on the board
/Address Bus/A11: U502.3 (QD); also elsewhere on the board
/Address Bus/A12: U502.4 (QE); also elsewhere on the board
/Address Bus/A13: U502.5 (QF); also elsewhere on the board
/Address Bus/A14: U502.6 (QG); also elsewhere on the board
/Address Bus/A15: U502.7 (QH); also elsewhere on the board
/Address Bus/A_OE_L: U501.13 (G), U502.13 (G); also elsewhere on the board
/Address Bus/A_RCK: U501.12 (RCLK), U502.12 (RCLK); also elsewhere on the board
/Address Bus/A_SCK: U501.11 (SRCLK), U502.11 (SRCLK); also elsewhere on the board
/Address Bus/A_SER: U501.14 (SER); also elsewhere on the board
/Address Bus/A_SER_QH: U501.9 (~QH), U502.14 (SER)
GND: C501.2, C502.2, U501.8 (GND), U502.8 (GND); also elsewhere on the board
unnamed: R501.1, U501.10 (SRCLR)
unnamed: R502.1, U502.10 (SRCLR)
VCC: C501.1, C502.1, R501.2, R502.2, U501.16 (VCC), U502.16 (VCC); also elsewhere on the board

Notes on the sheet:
Address Bus
Bypass capacitors for 74HC595 (one per IC)
A_SER Serial input for the shift registers. A_SCK Shift register clock input. Shifts input from A_SER on its rising edge. A_RCK Storage register clock input. Moves register contents to output latches on rising edge. A_OE_L Output enable for shift registers. When HIGH, the address pins will go into 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
Signal Descriptions
A future revision can remove the A_OE_L signal and instead just pull these pins low since the signal had to always be kept low in software anyway.

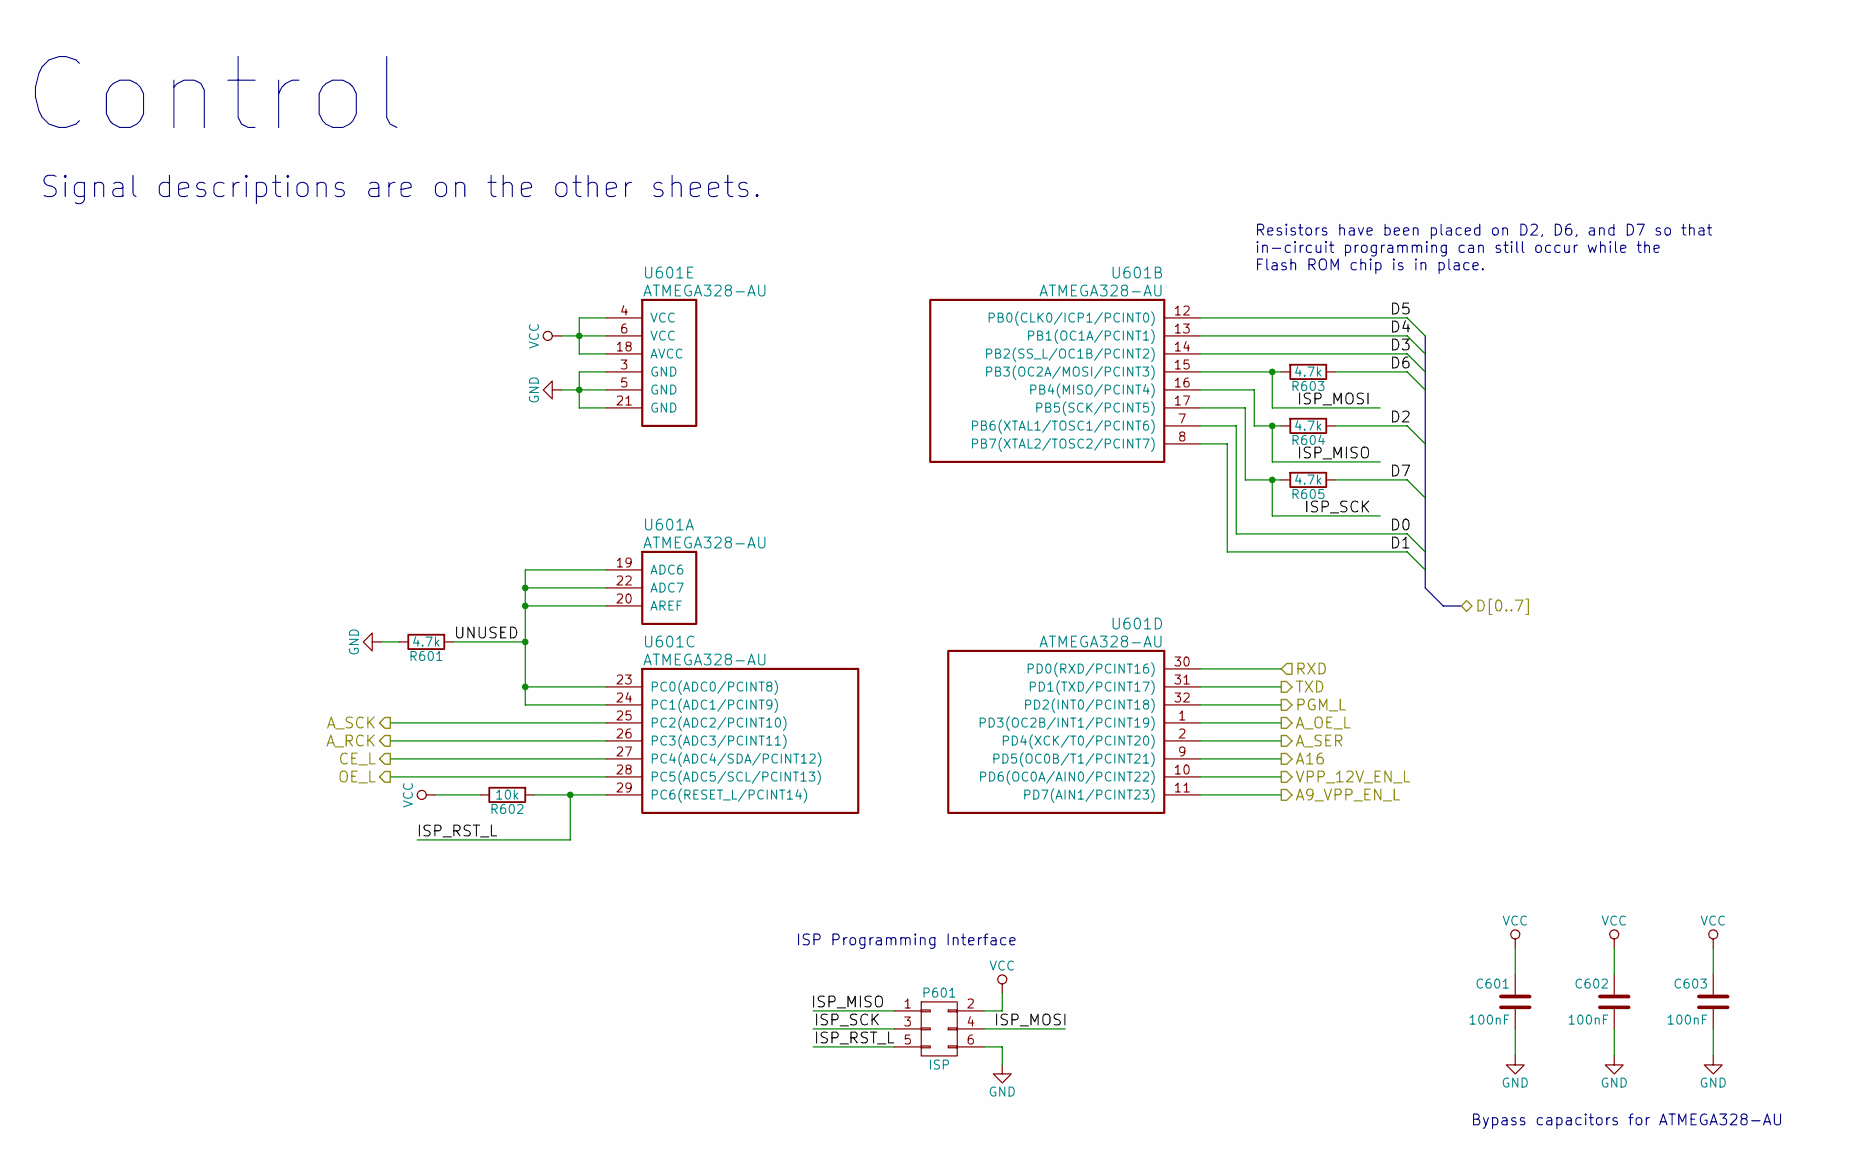
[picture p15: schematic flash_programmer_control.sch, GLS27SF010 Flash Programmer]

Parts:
C601, C602, C603: 100nF; R_0603_HandSoldering
P601: ISP; Pin_Header_Straight_2x03_Pitch2.54mm
R601, R603, R604, R605: 4.7k; R_0603_HandSoldering
R602: 10k; R_0603_HandSoldering
U601: ATMEGA328-AU; TQFP-32

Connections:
/12V PSU/VPP_12V_EN_L: U601.10 (PD6(OC0A/AIN0/PCINT22)); also elsewhere on the board
/Address Bus/A_OE_L: U601.1 (PD3(OC2B/INT1/PCINT19)); also elsewhere on the board
/Address Bus/A_RCK: U601.26 (PC3(ADC3/PCINT11)); also elsewhere on the board
/Address Bus/A_SCK: U601.25 (PC2(ADC2/PCINT10)); also elsewhere on the board
/Address Bus/A_SER: U601.2 (PD4(XCK/T0/PCINT20)); also elsewhere on the board
/COM1: U601.30 (PD0(RXD/PCINT16)); also elsewhere on the board
/COM2: U601.31 (PD1(TXD/PCINT17)); also elsewhere on the board
/Control/A9_VPP_EN_L: U601.11 (PD7(AIN1/PCINT23)); also elsewhere on the board
/Control/A16: U601.9 (PD5(OC0B/T1/PCINT21)); also elsewhere on the board
/Control/CE_L: U601.27 (PC4(ADC4/SDA/PCINT12)); also elsewhere on the board
/Control/D0: U601.7 (PB6(XTAL1/TOSC1/PCINT6)); also elsewhere on the board
/Control/D1: U601.8 (PB7(XTAL2/TOSC2/PCINT7)); also elsewhere on the board
/Control/D2: R604.1; also elsewhere on the board
/Control/D3: U601.14 (PB2(SS_L/OC1B/PCINT2)); also elsewhere on the board
/Control/D4: U601.13 (PB1(OC1A/PCINT1)); also elsewhere on the board
/Control/D5: U601.12 (PB0(CLK0/ICP1/PCINT0)); also elsewhere on the board
/Control/D6: R603.1; also elsewhere on the board
/Control/D7: R605.1; also elsewhere on the board
/Control/ISP_MISO: P601.1, R604.2, U601.16 (PB4(MISO/PCINT4))
/Control/ISP_MOSI: P601.4, R603.2, U601.15 (PB3(OC2A/MOSI/PCINT3))
/Control/ISP_RST_L: P601.5, R602.2, U601.29 (PC6(RESET_L/PCINT14))
/Control/ISP_SCK: P601.3, R605.2, U601.17 (PB5(SCK/PCINT5))
/Control/OE_L: U601.28 (PC5(ADC5/SCL/PCINT13)); also elsewhere on the board
/Control/PGM_L: U601.32 (PD2(INT0/PCINT18)); also elsewhere on the board
/Control/UNUSED: R601.2, U601.19 (ADC6), U601.20 (AREF), U601.22 (ADC7), U601.23 (PC0(ADC0/PCINT8)), U601.24 (PC1(ADC1/PCINT9))
GND: C601.2, C602.2, C603.2, P601.6, R601.1, U601.3 (GND), U601.5 (GND), U601.21 (GND); also elsewhere on the board
VCC: C601.1, C602.1, C603.1, P601.2, R602.1, U601.4 (VCC), U601.6 (VCC), U601.18 (AVCC); also elsewhere on the board

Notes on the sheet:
Bypass capacitors for ATMEGA328-AU
ISP Programming Interface
Control
Signal descriptions are on the other sheets.
Resistors have been placed on D2, D6, and D7 so that in-circuit programming can still occur while the Flash ROM chip is in place.

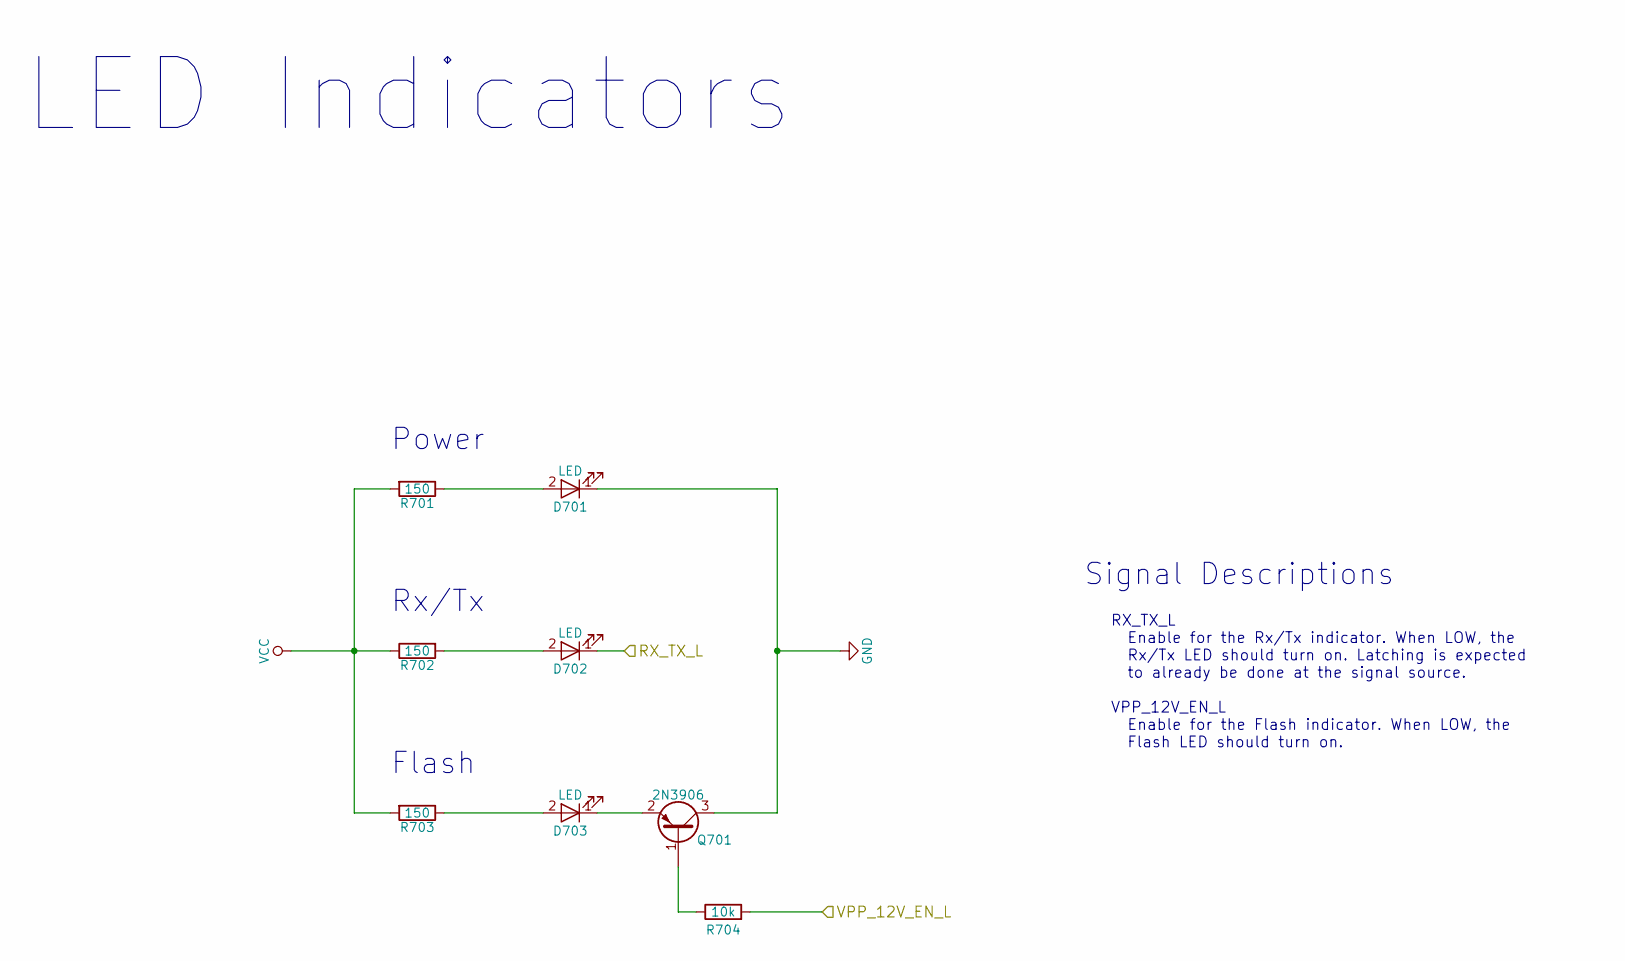
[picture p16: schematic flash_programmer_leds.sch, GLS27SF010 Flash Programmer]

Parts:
D701, D702, D703: LED; LED_0805
Q701: 2N3906; SOT-23_Handsoldering
R701, R702, R703: 150; R_0603_HandSoldering
R704: 10k; R_0603_HandSoldering

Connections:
/12V PSU/VPP_12V_EN_L: R704.2; also elsewhere on the board
/FTDI USB Serial Interface/RX_TX_L: D702.1 (K); also elsewhere on the board
GND: D701.1 (K), Q701.3 (C); also elsewhere on the board
unnamed: D701.2 (A), R701.1
unnamed: D702.2 (A), R702.2
unnamed: D703.1 (K), Q701.2 (E)
unnamed: D703.2 (A), R703.1
unnamed: Q701.1 (B), R704.1
VCC: R701.2, R702.1, R703.2; also elsewhere on the board

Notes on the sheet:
Rx/Tx
Power
Flash
LED Indicators
Signal Descriptions
RX_TX_L Enable for the Rx/Tx indicator. When LOW, the Rx/Tx LED should turn on. Latching is expected to already be done at the signal source. VPP_12V_EN_L Enable for the Flash indicator. When LOW, the Flash LED should turn on.

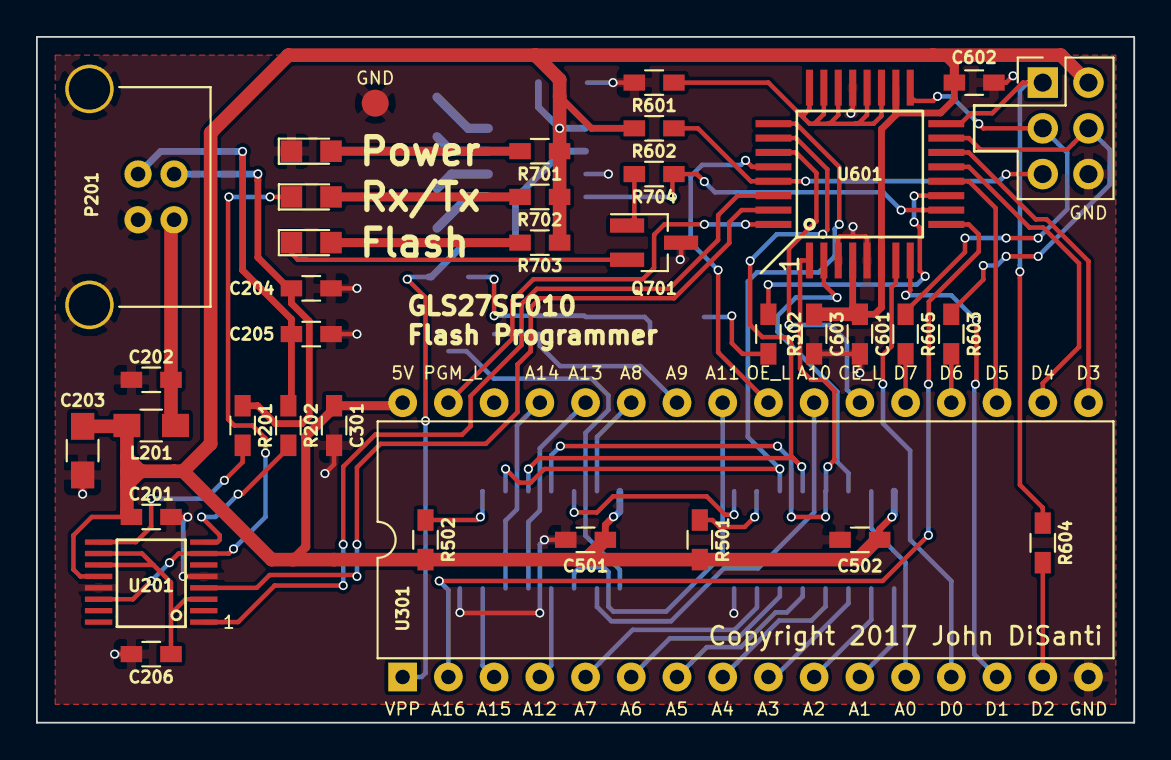
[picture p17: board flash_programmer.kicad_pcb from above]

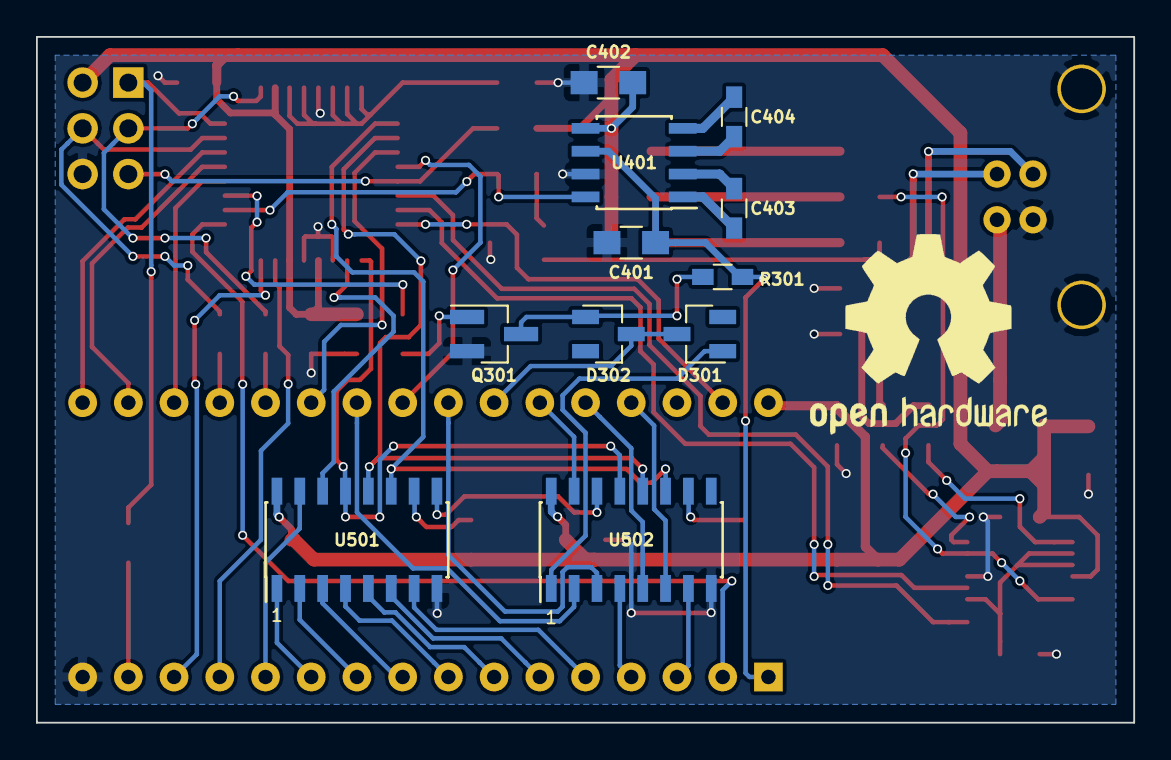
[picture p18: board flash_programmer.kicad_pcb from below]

Board: 2 copper layers, 61.0 x 38.1 mm, 48 parts (11 on the bottom side), 66 nets.

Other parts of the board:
GND: Measurement_Point_Round-SMD-Pad_Small

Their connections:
GND: GND.1; also elsewhere on the board

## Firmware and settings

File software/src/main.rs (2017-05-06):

//
// 128K 17-bit Addressed 32-pin Flash ROM Programmer
// Copyright 2017 John DiSanti
//
// Copyright and related rights are licensed under the Solderpad Hardware License, Version 0.51 (the "License");
// you may not use this file except in compliance with the License. You may obtain a copy of the License at
// http://solderpad.org/licenses/SHL-0.51. Unless required by applicable law or agreed to in writing, software,
// hardware and materials distributed under this License is distributed on an "AS IS" BASIS, WITHOUT WARRANTIES
// OR CONDITIONS OF ANY KIND, either express or implied. See the License for the specific language governing
// permissions and limitations under the License.
//

extern crate byteorder;
#[macro_use]
extern crate clap;
#[macro_use]
extern crate derive_error_chain;
extern crate error_chain;
extern crate serial;
extern crate term;

mod constants;
mod error;
mod read;
mod write;
mod progress;
mod serial_port;

use error::*;
use std::process::exit;

fn handle_result(result: Result<()>) {
    if let Err(err) = result {
        println!("{}", err);
        exit(1);
    }
}

fn main() {
    let mut app = clap_app!(flash_programmer =>
        (version: "1.0")
        (author: "Copyright 2017 John DiSanti")
        (about: "128K 17-bit Addressed 32-pin Flash ROM Programmer Software")
        (@subcommand read =>
            (about: "reads contents of flash ROM to file")
            (@arg DEVICE: +required "Sets the serial port to use")
            (@arg OUTPUT: +required "Sets the output file to write to"))
        (@subcommand write =>
            (about: "writes the contents of a file to the ROM")
            (@arg DEVICE: +required "Sets the serial port to use")
            (@arg INPUT: +required "Sets the input file to read from")));

    let matches = app.clone().get_matches();
    if let Some(ref matches) = matches.subcommand_matches("read") {
        handle_result(read::read_rom(matches.value_of("DEVICE").unwrap(),
                                     matches.value_of("OUTPUT").unwrap()));
    } else if let Some(ref matches) = matches.subcommand_matches("write") {
        handle_result(write::write_rom(matches.value_of("DEVICE").unwrap(),
                                       matches.value_of("INPUT").unwrap()));
    } else {
        drop(app.print_help());
    }
}

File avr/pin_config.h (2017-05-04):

//
// 128K 17-bit Addressed 32-pin Flash ROM Programmer
// Copyright 2017 John DiSanti
//
// Copyright and related rights are licensed under the Solderpad Hardware License, Version 0.51 (the "License");
// you may not use this file except in compliance with the License. You may obtain a copy of the License at
// http://solderpad.org/licenses/SHL-0.51. Unless required by applicable law or agreed to in writing, software,
// hardware and materials distributed under this License is distributed on an "AS IS" BASIS, WITHOUT WARRANTIES
// OR CONDITIONS OF ANY KIND, either express or implied. See the License for the specific language governing
// permissions and limitations under the License.
//

#ifndef PIN_CONFIG_H_
#define PIN_CONFIG_H_

/* Pin manipulation macros */

#define _SET(type, name, bit)           type ## name  |= _BV(bit)
#define _CLEAR(type, name, bit)         type ## name  &= ~ _BV(bit)
#define _TOGGLE(type, name, bit)        type ## name  ^= _BV(bit)
#define _GET(type, name, bit)           ((type ## name >> bit) &  1)
#define _PUT(type, name, bit, value)    type ## name = (type ## name & (~_BV(bit))) | ((1 & (uint8_t) (value)) << (bit))

#define INPUT     0
#define OUTPUT    1

#define SET_PIN_MODE(pin, mode)         _PUT(DDR, pin, mode)
#define SET_OUTPUT(pin)                 _SET(DDR, pin)
#define SET_INPUT(pin)                  _CLEAR(DDR, pin)
#define SET_PIN_HIGH(pin)               _SET(PORT, pin)
#define SET_PIN_LOW(pin)                _CLEAR(PORT, pin)
#define TOGGLE_PIN(pin)                 _TOGGLE(PORT, pin)
#define GET_PIN(pin)                    _GET(PIN, pin)
#define SET_PIN(pin, value)             _PUT(PORT, pin, value)
#define SET_PULLUP(pin)                 _SET(PORT, pin)
#define CLEAR_PULLUP(pin)               _CLEAR(PORT, pin)

/* Pin configs */

// Port B
#define PIN_D5                B,0
#define PIN_D4                B,1
#define PIN_D3                B,2
#define PIN_D6                B,3
#define PIN_D2                B,4
#define PIN_D7                B,5
#define PIN_D0                B,6
#define PIN_D1                B,7

// Port C
#define PIN_UNUSED_PC0        C,0
#define PIN_UNUSED_PC1        C,1
#define PIN_A_SCK             C,2
#define PIN_A_RCK             C,3
#define PIN_CE_L              C,4
#define PIN_OE_L              C,5
#define PIN_ISP_RST_L         C,6
#define PIN_UNUSED_PC7        C,7

// Port D
#define PIN_RXD               D,0
#define PIN_TXD               D,1
#define PIN_PGM_L             D,2
#define PIN_A_OE_L            D,3
#define PIN_A_SER             D,4
#define PIN_A16               D,5
#define PIN_VPP_12V_EN_L      D,6
#define PIN_A9_VPP_EN_L       D,7

void init_pins();
void data_output_mode();
void data_input_mode();
void set_address(uint32_t address);
void set_data(uint8_t data);

void reset_12v();
void set_12v_vpp();
void set_12v_vpp_a9();

#endif /* PIN_CONFIG_H_ */

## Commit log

2017-02-11 Fix pin numbers on 2n3906
    The Base and Emitter were swapped which caused error in PCB design and
    manufacture. Fixing them for the future.
2017-02-11 Fix errors in PCB design
    Fixed the pin order on the 2n3906 transistor for the flash indicator LED.
    Corrected positions of labels for C15 and R10.
    [flash_programmer.kicad_pcb]
2017-03-10 Redo PCB: fix errors and shrink
    [flash_programmer.kicad_pcb, flash_programmer.sch, flash_programmer_debug.sch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]
2017-03-10 Revise the PCB
    Added a ground test point, and enlarged annular rings around vias.
    [flash_programmer.kicad_pcb]
2017-03-10 Revise the silkscreens on the PCB
    [flash_programmer.kicad_pcb]
2017-03-10 Fix flash writing
    Flash erase does not work. Turns out we need 12V on the A9 line (which the
    current revision does not have capability for).
    [main.cpp]
2017-03-10 Work in progress: Add `12V capability to A9
    [flash_programmer.sch, flash_programmer_flash_chip.sch]
2017-03-10 Work in progress: Come up with untested A9_P circuit
    [flash_programmer_flash_chip.sch]
2017-03-10 Redo the A9_P circuit with a P-channel MOSFET to avoid voltage drop
    [flash_programmer.sch, flash_programmer_flash_chip.sch, flash_programmer_ftdi.sch]
2017-03-10 Redraw schematic for clarity
    [flash_programmer.sch, flash_programmer_control.sch, flash_programmer_flash_chip.sch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]
2017-03-10 Associate footprints and correct pin orders for transistors
    [flash_programmer_control.sch, flash_programmer_flash_chip.sch, flash_programmer_ftdi.sch]
2017-03-11 Bug fix and more schematic cleanup
    The A9_VPP circuit wouldn't work in all cases, so I completely redid it and
    it's simpler now.
    Also started splitting up the schematic into even more sheets, and sprinkled in
    some TODO comments.
    [flash_programmer.kicad_pcb, flash_programmer.sch, flash_programmer_12v_source.sch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]
2017-03-12 More schematic clean up
    [atmega328p.csv, flash_programmer.sch, flash_programmer_12v_source.sch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]
2017-03-13 Create PCB for latest schematic design
    [flash_programmer.kicad_pcb, flash_programmer_control.sch]
2017-03-26 Fix a bug that prevented reading the last block
    [main.cpp, pin_config.h, read.cpp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]
2017-03-27 Fix most write issues
    The first byte of the ROM is still written incorrectly for some reason.
    [main.cpp, main.rs, read.cpp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]
2017-05-03 Revised fab layers for easier assembly reference
    [flash_programmer.kicad_pcb]
2017-05-03 Bug fixes for the microcontroller code
    - Fix (almost) infinite loop due to unsigned int
    - Wait longer for 12V assertion which seems to have
    fixed the first two bytes not getting written
    - Don't disable output on shift registers as that
    prevents the second register from ever having a value
    [main.cpp]
2017-05-06 Cleaned up the code in software/
    Added comments, proper error handling, and generally tidied up the code
    [main.rs]
2017-05-06 Apply license to schematic files
    [flash_programmer.sch, flash_programmer_12v_source.sch, flash_programmer_address_bus.sch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]
2017-05-06 Correction: ATMEGA328P -> ATMEGA328-AU
    [atmega328au.csv, flash_programmer.kicad_pcb, flash_programmer.sch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]
2017-05-06 Add license and OSHW logo to PCB
    [flash_programmer.kicad_pcb]
2017-05-06 Add PDFs of schematic and PCB, and add BOM file
    [BOM.csv, flash_programmer.kicad_pcb]
